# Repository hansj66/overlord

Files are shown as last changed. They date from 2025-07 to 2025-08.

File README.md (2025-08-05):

# Overlord Robot Controller

## Overview

"Overlord" is a carrier board for the Raspberry Pi Compute module 5. The board facilitates easy integration with [Xiaomi Cybergear](https://www.mi.com/cyber-gear) motors and half duplex Dynamixels, like the [AX-12A](https://emanual.robotis.com/docs/en/dxl/ax/ax-12a/), [MX-12W](https://emanual.robotis.com/docs/en/dxl/ax/ax-12a/) servos.

The carrier board has an onboard can controller, can transciever, a 9 axis IMU with 100Hz sensor fusion, half duplex line driver circuitry for Dynamixel servos and has an acceptable power input range from 5 to 36V.

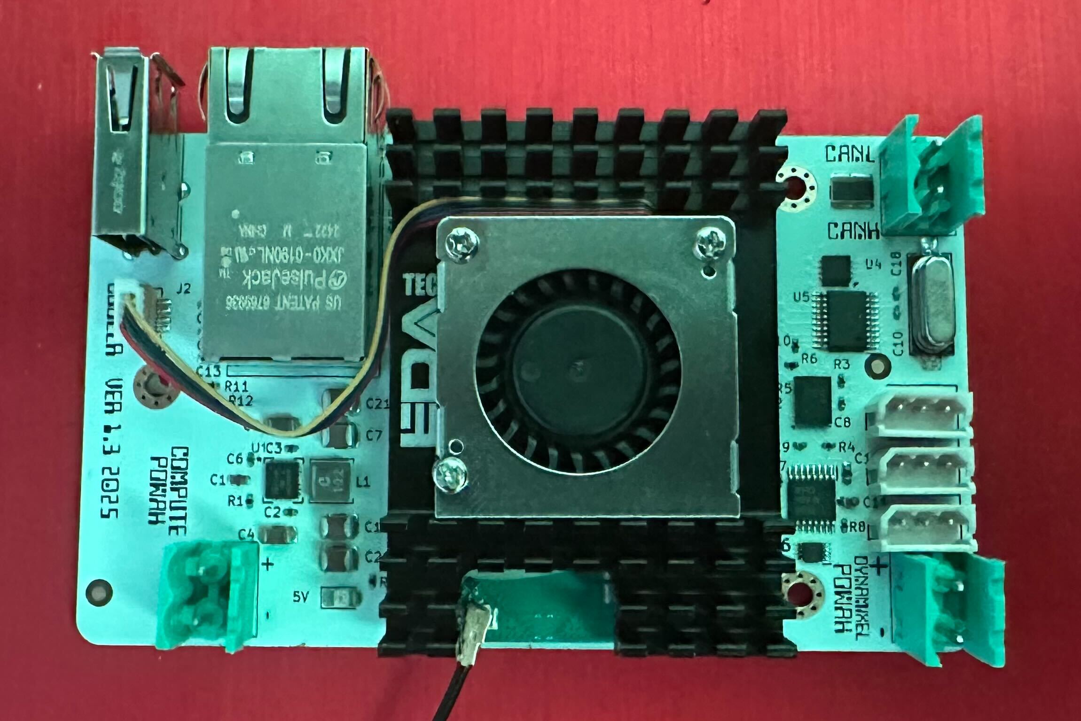
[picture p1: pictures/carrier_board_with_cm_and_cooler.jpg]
Carrier board with CM5 and active cooler


This repository contains:
* All the necessary KiCad schematics, PCB layout and gerber files for making copies of the carrier board.
* boot/firmware/config.txt (for the necessary boot overlays and IO mappings).
* Go code examples for communicating with Dynamixels, Cybergears and the IMU.
* Go code examples for how to implement remote control via a bluetooth gamepad, FrSky [XSR-SIM](https://www.frsky-rc.com/product/xsr-sim/) (or similar HID device).

## Licensing
This is open hardware and software. Licensing terms can be found [here](LICENSE.md).

## Getting started

In addition to the carrier board, you will need a 
* [Compute module 5](https://datasheets.raspberrypi.com/cm5/cm5-datasheet.pdf). 
* [Raspberry Pi Development Kit for Compute Module 5](https://www.raspberrypi.com/products/cm5-dev-kit/)
* If you plan to use wifi, I strongly suggest getting the official Raspberry Pi Compute module 4/5 antenna kit.
* A passive or active cooler for the CM5. If using an active cooler, attach the FAN connector to the "COOLER" socket on the carrier board.

### Programming the CM5

1. The compute module has to be flashed with an operating system before it can be used. Information on how to do this is available in the ["Compute Module Hardware"](https://www.raspberrypi.com/documentation/computers/compute-module.html#flash-compute-module-emmc) section on the offical [raspberrypi.com](https://www.raspberrypi.com/) site. Remember to enable SSH in the OS customisation settings before flashing the module.
1. Mount the CM5 in the carrier board and attach a battery or power supply to the "COMPUTE POWAH" port. Observe polarity. There is no reverse polarity protection circuitry. Reversing polarity will in all likelyhood fry the carrier board.
1. The blue LED on the carrier board will light up, indicating that it has 5V power. 
1. The CM5 will require a few seconds to boot before you can ssh in. (Tip: create an .ssh folder under the CM5 home folder and copy your public key to ./ssh/authorized_keys. You can then "ssh hostname" without having to type in a password)
1. The compute module will announce itself on the network. Given a "hostname", you should now be able to "ssh hostname" to get shell access.
1. Once you have shell access, run "sudo raspi-config" to enable i2c, spi and UART (enable serial port hardware, but not serial shell).
1. Now you can "sudo vi /boot/firmware/config.txt. Update the config.txt according to the [config.txt](./config/config.txt) in this repository. 
1. Run "sudo reboot now" to reboot the module. This makes sure that the correct overlays are loaded and that the GPIO mappings are correct.

You are now all set to start playing around with the board.

## Configuration and code examples

* [Remote control](./firmware/examples/remote-control/README.md)
* [Dynamixel](./firmware/examples/dynamixel/README.md)
* [Xiaomi Cybergear](./firmware/examples/cybergear/README.MD)
* [IMU](./firmware/examples/imu/README.md)

## Networking

This board was designed for simplicity and ease of use with the primary goal being actuator control and balancing. Apart from the onboard IMU, there is no sensing or GPIO access. It is however possible to directly connect the board to another Pi or any other board that supports Auto MDI-X directly using a standard ethernet cable. Access to GPIO, camera etc can then be implemented via a simple tcp client/server.

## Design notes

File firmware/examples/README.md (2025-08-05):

# Overview

The firmware examples aim to demonstrate how to communicate with the hardware at the simplest possible level.

Consider the code samples as examples on how to communicate with peripherals board, not detailed tutorials for how to use Dynamixel servos, Cybergears or the BNO055 IMU etc. The README files accompanying each sample contains a resources chapter with links to relevant documentation and data sheets where control registers, commands and frame formats are documented in detail.

All firmware examples are written in Go, but the same examples are trivial to implement in other languages (C, C++, Python etc)

The example code together with online protocol documentation should be enough to get you started.

1. [Cybergear positioning example](./cybergear/README.MD)
1. [Dynamixel network scan example](./dynamixel/README.md)
1. [IMU example](./imu/README.md)
1. [Remote control example](./remote-control/README.md)

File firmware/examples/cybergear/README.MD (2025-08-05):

# Getting started - Xiaomi Cybergear

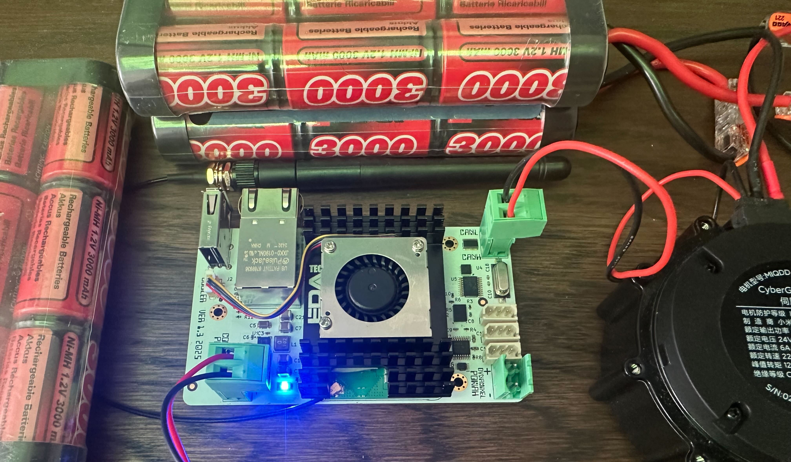
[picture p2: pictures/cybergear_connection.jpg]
cybergear connection


## Verifying that the can interface is ok

1. Install can utils

```sh
sudo apt install can-utils
```

2. Verify that the MCP2515 driver is initialized

```sh
dmesg | grep -i mcp
```
This should generate the following response:
```sh
mcp251x spi0.0 can0: MCP2515 successfully initialized.
```

3. Bring up can0.
```sh
sudo ip link set can0 up type can bitrate 1000000
```

## Initial test

With the board still powered up (battery / powersupply) connected to the "COMPUTE POWAH" port.

1. Connect the thin red wire from the Amass XT30(2+2) connector to CANH on the board.
2. Connect the thin black wire from the Amass XT30(2+2) connector to CANL on the board
3. Run the following command from the ssh shell

```sh
candump can0
```

candump is now running. 

Now you can connect power to the Cybergear via the thick red and black wires on the Amass XT30(2+2) connector. You should now see the following output from candump (0x7F is the default motor address):

```sh
can0  00007FFE   [8]  41 11 31 31 30 33 31 0A
```

### Code examples

* [position example README](./position/README.md)
* [position example code](./position/position.go)

### Resources

* [English translation of the Cybergear manual](https://github.com/belovictor/cybergear-docs/blob/main/instructionmanual/instructionmanual.md). This contains a description of the frame format and commands.
* [Open ELAB manual](https://openelab.io/blogs/learn/xiaomi-cybergear-motor-driver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)

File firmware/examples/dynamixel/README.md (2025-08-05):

# Getting started - Dynamixel

## Parametrization

Dynamixel servos have EEPROM + RAM control tables for parametrization (ID, baud rate, voltage limits etc). Since all servos are daisy chained and connected to the same communication bus, you will have to configure the servo ID and communication baud rate for each servo. This can be done in code, using [DYNAMIXEL protocol 2.0](https://emanual.robotis.com/docs/en/dxl/protocol2/) for AX-12A servos or [DYNAMIXEL protocol 1.0](https://emanual.robotis.com/docs/en/dxl/protocol1/) for MX-12W servos.

Since it is relatively easy to shoot yourself in the foot when parametrizing these servos (by changing baud rate etc), I highly recommend getting hold of a [U2D2 USB Communication converter](https://emanual.robotis.com/docs/en/parts/interface/u2d2/). Servo power has to be provided externally. You can use a separate power distributuion board together with the U2D2 when parametrizing the servos, or you can connect the U2D2 to the CM5 carrier board.

1. Connect the U2D2 to one of the dynamixel sockets on the carrier board.
1. Connect the U2D2 to your computer using a USB micro B to USBA cable.
1. Connect your servo to one of the remaining ports (multiple servos can be connected in serial by daisy chaining them).
1. Connect a battery pack or power supply to the "DYNAMIXEL POWAH" connector. Observe polarity, since this feeds directly into the servo power line. Do not connect anything to "COMPUTE POWAH" when doing this, since the carrier board just acts as a power distribution board / hub for the U2D2 when we parametrize the control tables.

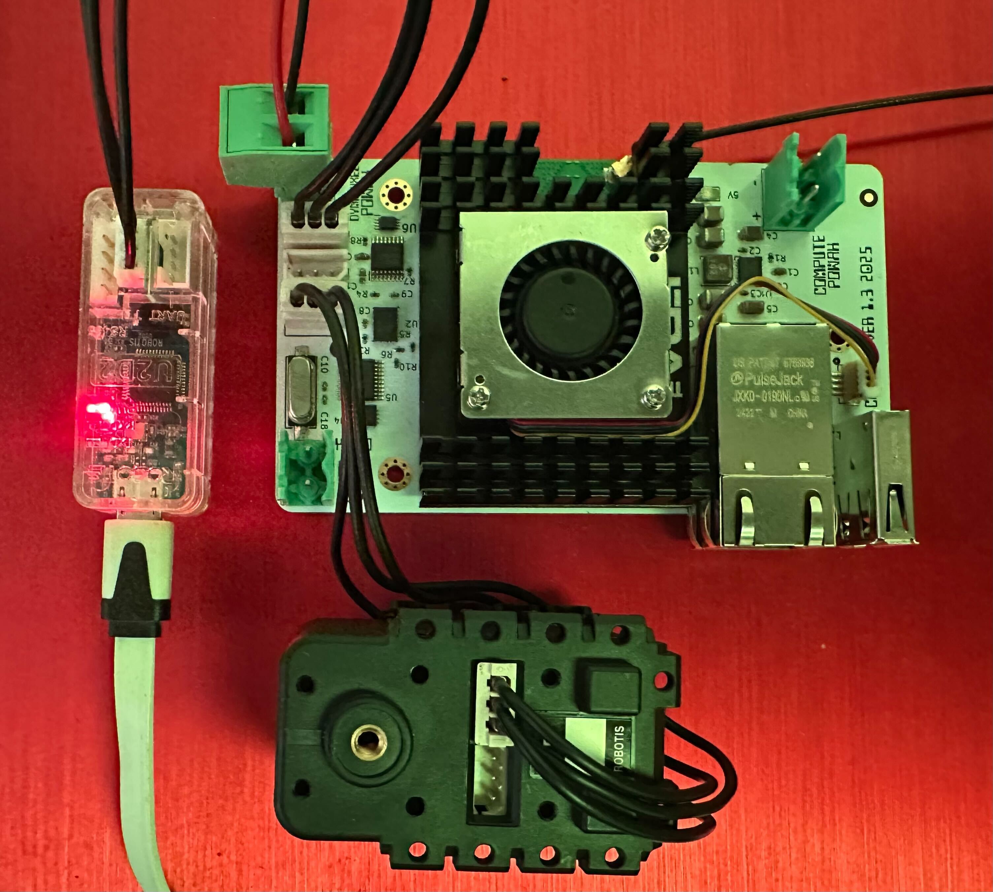
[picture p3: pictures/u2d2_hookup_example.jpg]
U2D2 hookup example


Once everything is hooked up and servo power is applied, you can use [Dynamixel Wizard](https://emanual.robotis.com/docs/en/software/dynamixel/dynamixel_wizard2/) to scan for servos in the network and also configure them (ID, baud rate etc)

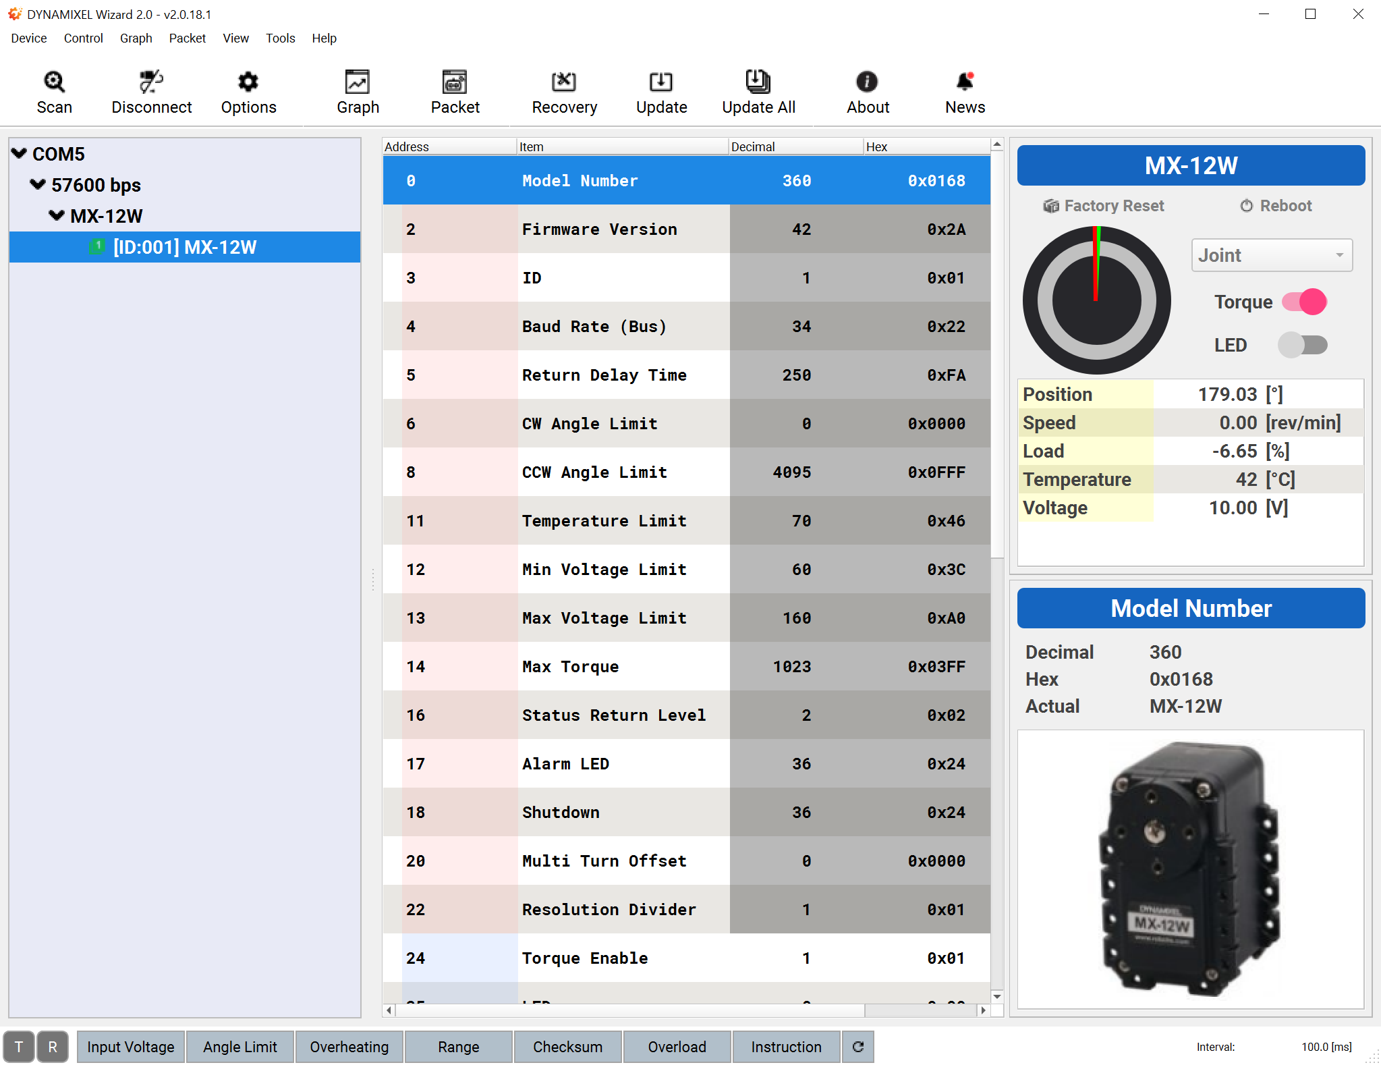
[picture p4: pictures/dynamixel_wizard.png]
Dynamixel wizard screen shot


> Note: If you are feeling brave, it is entirely possible to do this parametrization in code, but that means that someone (most likely you) will have to write a bit of extra code before you can play around with the servos and the controller board:)

### Code examples

* [Network scan example README](./scan/README.md)
* [Network scan example code](./scan/scan.go)

### Resources

* [Dynamixel SDK](https://emanual.robotis.com/docs/en/software/dynamixel/dynamixel_sdk/overview/)
* [Dynamixel Protocol 1.0](https://emanual.robotis.com/docs/en/dxl/protocol1/)
* [Dynamixel Protocol 2.0](https://emanual.robotis.com/docs/en/dxl/protocol2/)
* [Dynamxiel Wizard](https://emanual.robotis.com/docs/en/software/dynamixel/dynamixel_wizard2/)
* [U2D2 interface](https://emanual.robotis.com/docs/en/parts/interface/u2d2/)

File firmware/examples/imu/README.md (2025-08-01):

# IMU

Note: AFAIK there is no kernel driver available for the BNO055 IMU, so the low level i2c interface must be used to communicate witht the IMU.

## Cross compiling the Go example code

1. Set the following environment variables (syntax may vary depending on your OS flavour),

```sh
GOOS=linux 
GOARCH=arm64 
GOARM=8
```

2. Compile the example program 

```sh
go build -o euler
```

3. Upload the binary to your board using scp (host name is "overlord" in the example)

```sh
scp euler overlord:
```

4. ssh to your board and run the euler program (chmod +x if it isn't executable)

```sh
ssh overlord
chmod +x euler
./euler
```

Move the carrier board around to see the heading vector change.
Example output:

```sh
2025/08/01 16:47:14 INFO BNO055 heading="Heading: 357.75°, Roll: 4066.62°, Pitch: 11.19°\n"
2025/08/01 16:47:14 INFO BNO055 heading="Heading: 359.56°, Roll: 4037.38°, Pitch: 43.06°\n"
2025/08/01 16:47:15 INFO BNO055 heading="Heading: 358.31°, Roll: 4027.44°, Pitch: 21.00°\n"
2025/08/01 16:47:15 INFO BNO055 heading="Heading: 340.94°, Roll: 4033.19°, Pitch: 4028.31°\n"
2025/08/01 16:47:16 INFO BNO055 heading="Heading: 76.75°, Roll: 4048.81°, Pitch: 4020.38°\n"
2025/08/01 16:47:16 INFO BNO055 heading="Heading: 81.56°, Roll: 4067.94°, Pitch: 4029.06°\n"
2025/08/01 16:47:17 INFO BNO055 heading="Heading: 73.81°, Roll: 4089.69°, Pitch: 4020.50°\n"
2025/08/01 16:47:17 INFO BNO055 heading="Heading: 74.81°, Roll: 4085.62°, Pitch: 4060.06°\n"
2025/08/01 16:47:18 INFO BNO055 heading="Heading: 82.56°, Roll: 4089.88°, Pitch: 1.00°\n"
```

### Resources

* [BNO055 Datasheet](https://www.bosch-sensortec.com/media/boschsensortec/downloads/datasheets/bst-bno055-ds000.pdf)
* [BNO055 no-os driver](https://github.com/boschsensortec/BNO055_SensorAPI)

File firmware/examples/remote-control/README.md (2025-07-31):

# Remote control

An ordinary gamepad can be used for remote control of the carrier board. In this example we'll use a generic gamepad with a bluetooth USB dongle. This will appear as a HID device on the CM5 and will be accessible as /dev/input/js0

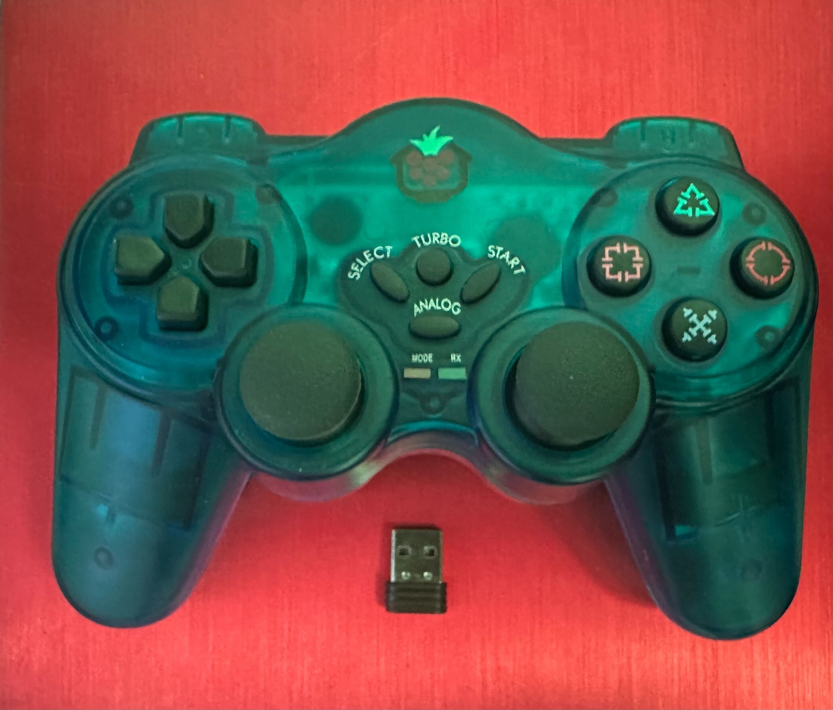
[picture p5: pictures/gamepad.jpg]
Generic gamepad with USB dongle


The example program is meant as an illustration of how to access the input HID device and decode events from the gamepad. 

## Cross compiling the Go example code

1. Set the following environment variables (syntax may vary depending on your OS flavour),

```sh
GOOS=linux 
GOARCH=arm64 
GOARM=8
```

2. Compile the example program 

```sh
go build -o joysticktest
```

3. Upload the binary to your board using scp (host name is "overlord" in the example)

```sh
scp joysticktest overlord:
```

4. ssh to your board and run the joysticktest program (chmod +x if it isn't executable)

```sh
ssh overlord
chmod +x joysticktest
./joysticktest
```

The program will list the status of all gamepad buttons and axis. Pressing a button or moving one of the axis will result in an event that is listed on the screen.

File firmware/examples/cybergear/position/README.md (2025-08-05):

## Positioning example

This example first runs the motor in speedmode with two different speeds / directions and then runs the motor in positioning mode where it toggles between 0 and +90° five times.

## Cross compiling and running the Go example code

1. Set the following environment variables (syntax may vary depending on your OS flavour),

```sh
GOOS=linux 
GOARCH=arm64 
GOARM=8
```

2. Compile the example program 

```sh
go build -o position
```

3. Upload the binary to your board using scp (host name is "overlord" in the example)

```sh
scp position overlord:
```

4. Bring up the CAN bus

```sh
sudo ip link set can0 up type can bitrate 1000000
```

4. ssh to your board and run the scan program (chmod +x if it isn't executable)

```sh
ssh overlord
chmod +x position
./scan
```

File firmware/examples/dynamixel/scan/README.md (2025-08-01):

# Dynamixel Protocol 1.0 network scan

This example demonstrates how to scan the valid servo ID range. This is done by sending a ping packet to all addresses between 0 and 253. A response packet indicates that a servo has been found in the network

This example is using Dynamixel protocol 1.0 for sending ping packets. The example can be modified for using protocol 2.0 by changing the frame format and CRC calculation. Protocol 2.0 ping is described in section 5.1.3.2 in this manual: https://emanual.robotis.com/docs/en/dxl/protocol2/

## Cross compiling the Go example code

1. Set the following environment variables (syntax may vary depending on your OS flavour),

```sh
GOOS=linux 
GOARCH=arm64 
GOARM=8
```

2. Compile the example program 

```sh
go build -o scan
```

3. Upload the binary to your board using scp (host name is "overlord" in the example)

```sh
scp scan overlord:
```

4. ssh to your board and run the scan program (chmod +x if it isn't executable)

```sh
ssh overlord
chmod +x scan
./scan
```

Assuming that the network contains one servo with ID=1, the output will be on the form:

```sh
2025/08/01 14:09:41 INFO Opening serialport port=/dev/ttyAMA0
2025/08/01 14:09:41 INFO Serial port opened successfully
2025/08/01 14:09:41 INFO DXL DIR pin=GPIO22
PING id:0 - no response
PING id:1 - response packet: FFFF010200FC
PING id:2 - no response
PING id:3 - no response
...
```

The same protocol can be used for reading and writing to EEPROM and RAM control table parameters
Protocol specifications:
 - 1.0: https://emanual.robotis.com/docs/en/dxl/protocol1/
 - 2.0: https://emanual.robotis.com/docs/en/dxl/protocol2/

Note:

1. The carrier board has to be powered through the "COMPUTE POWAH" connector (5-36V).
1. The dynamixel servos has to be powered through the "DYNAMIXEL POWAH". This power rail only feeds the
   servos via the dynamixel bus. Please refer to the servo manuals regarding min/max voltages. Exceeding
   the rated servo voltages will permanently damage your servos.

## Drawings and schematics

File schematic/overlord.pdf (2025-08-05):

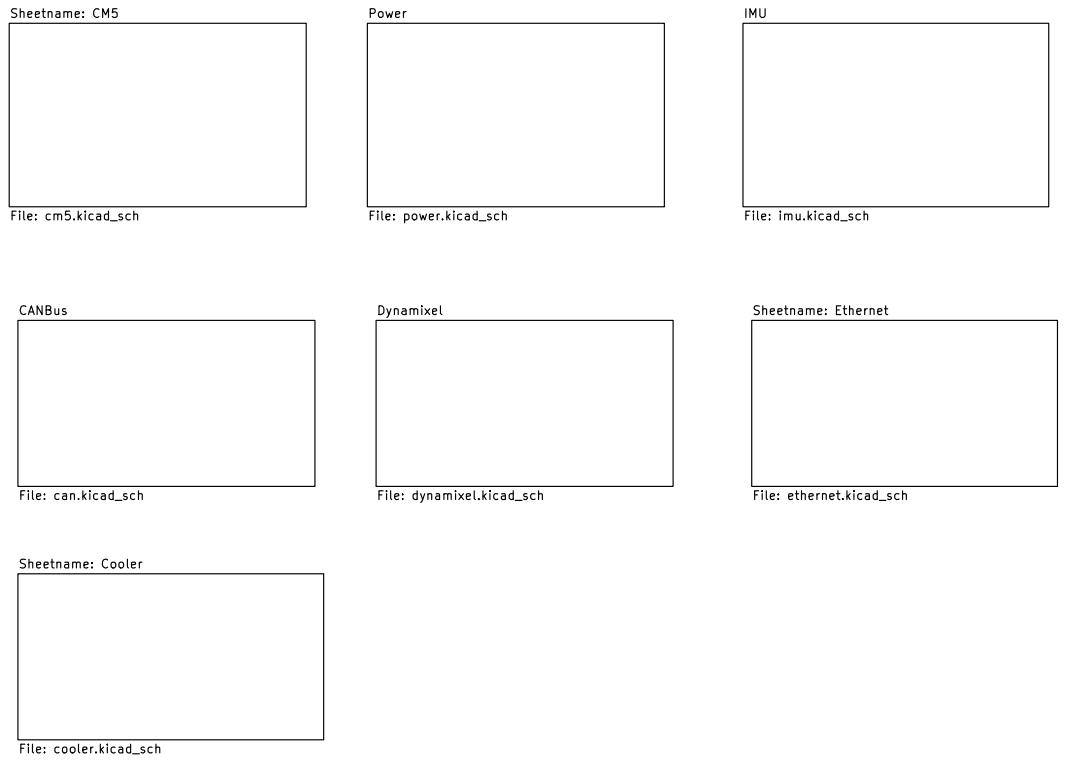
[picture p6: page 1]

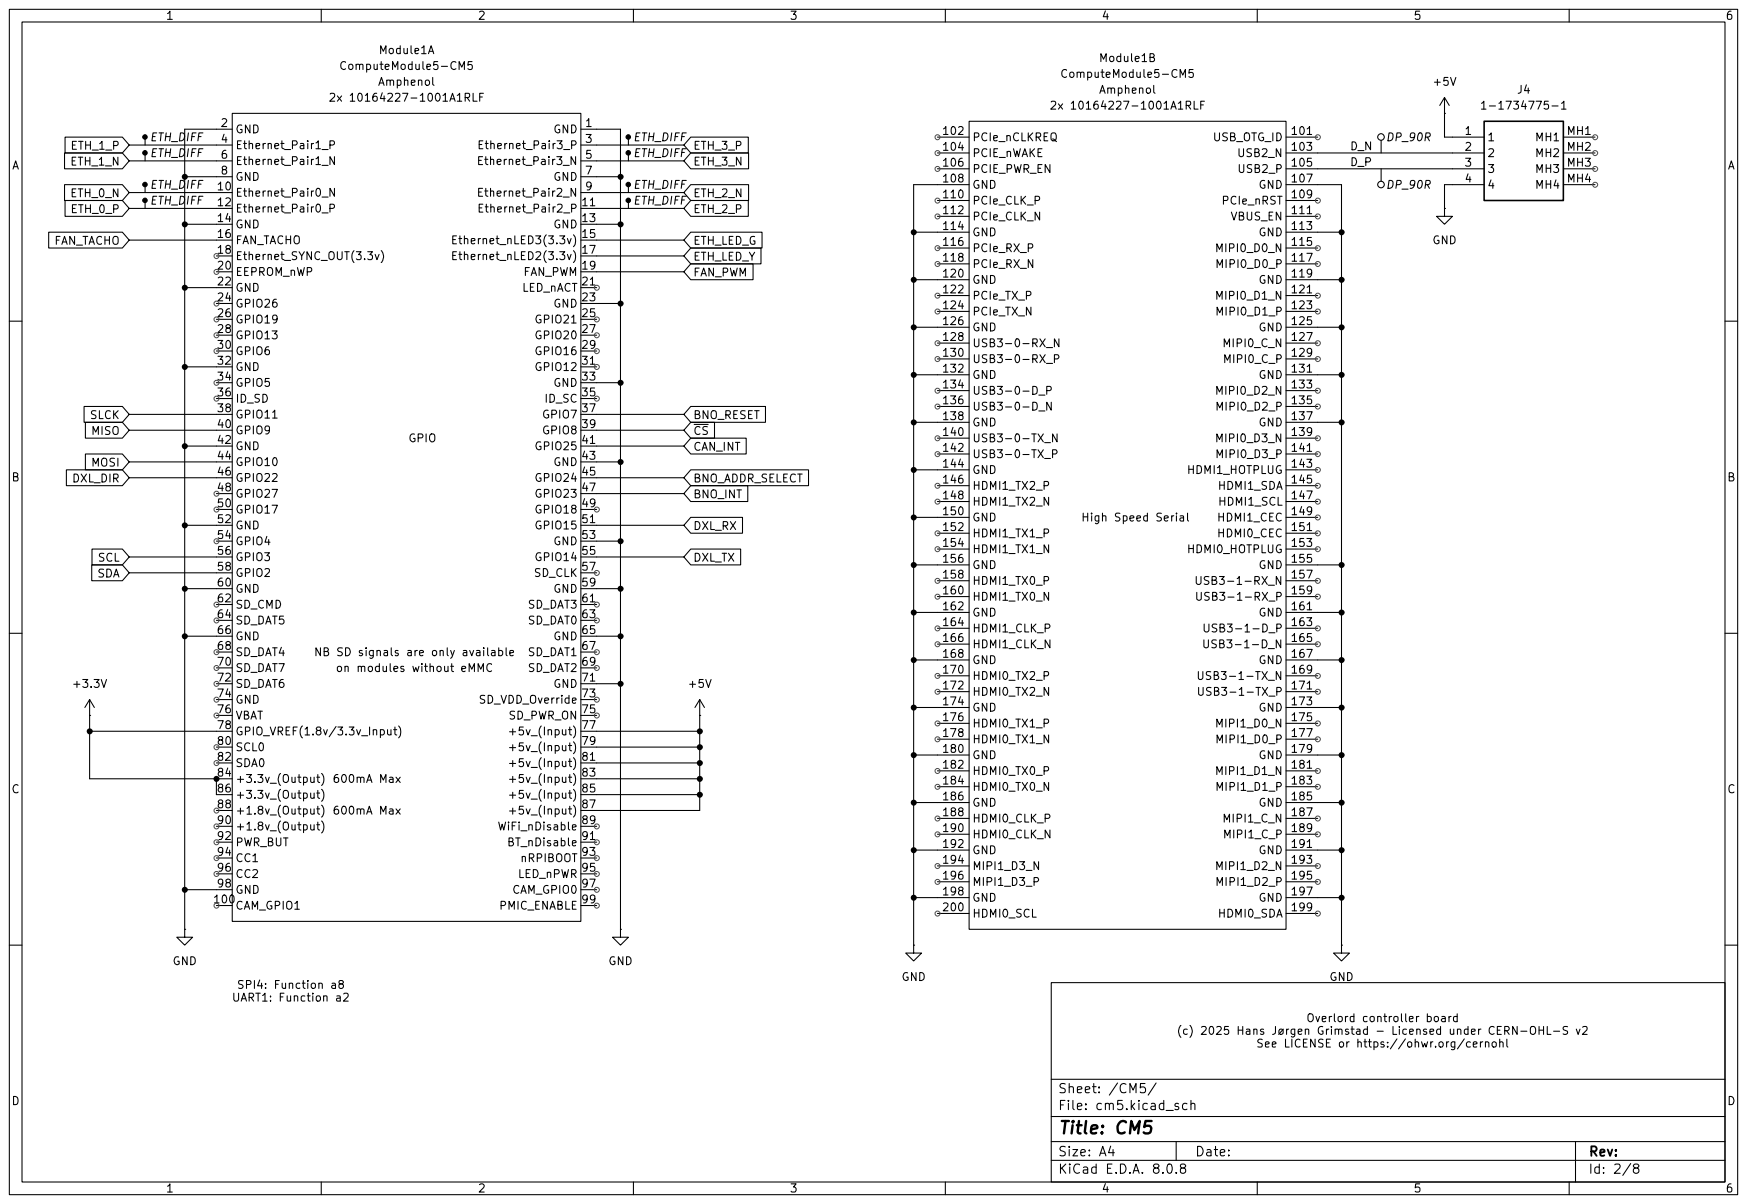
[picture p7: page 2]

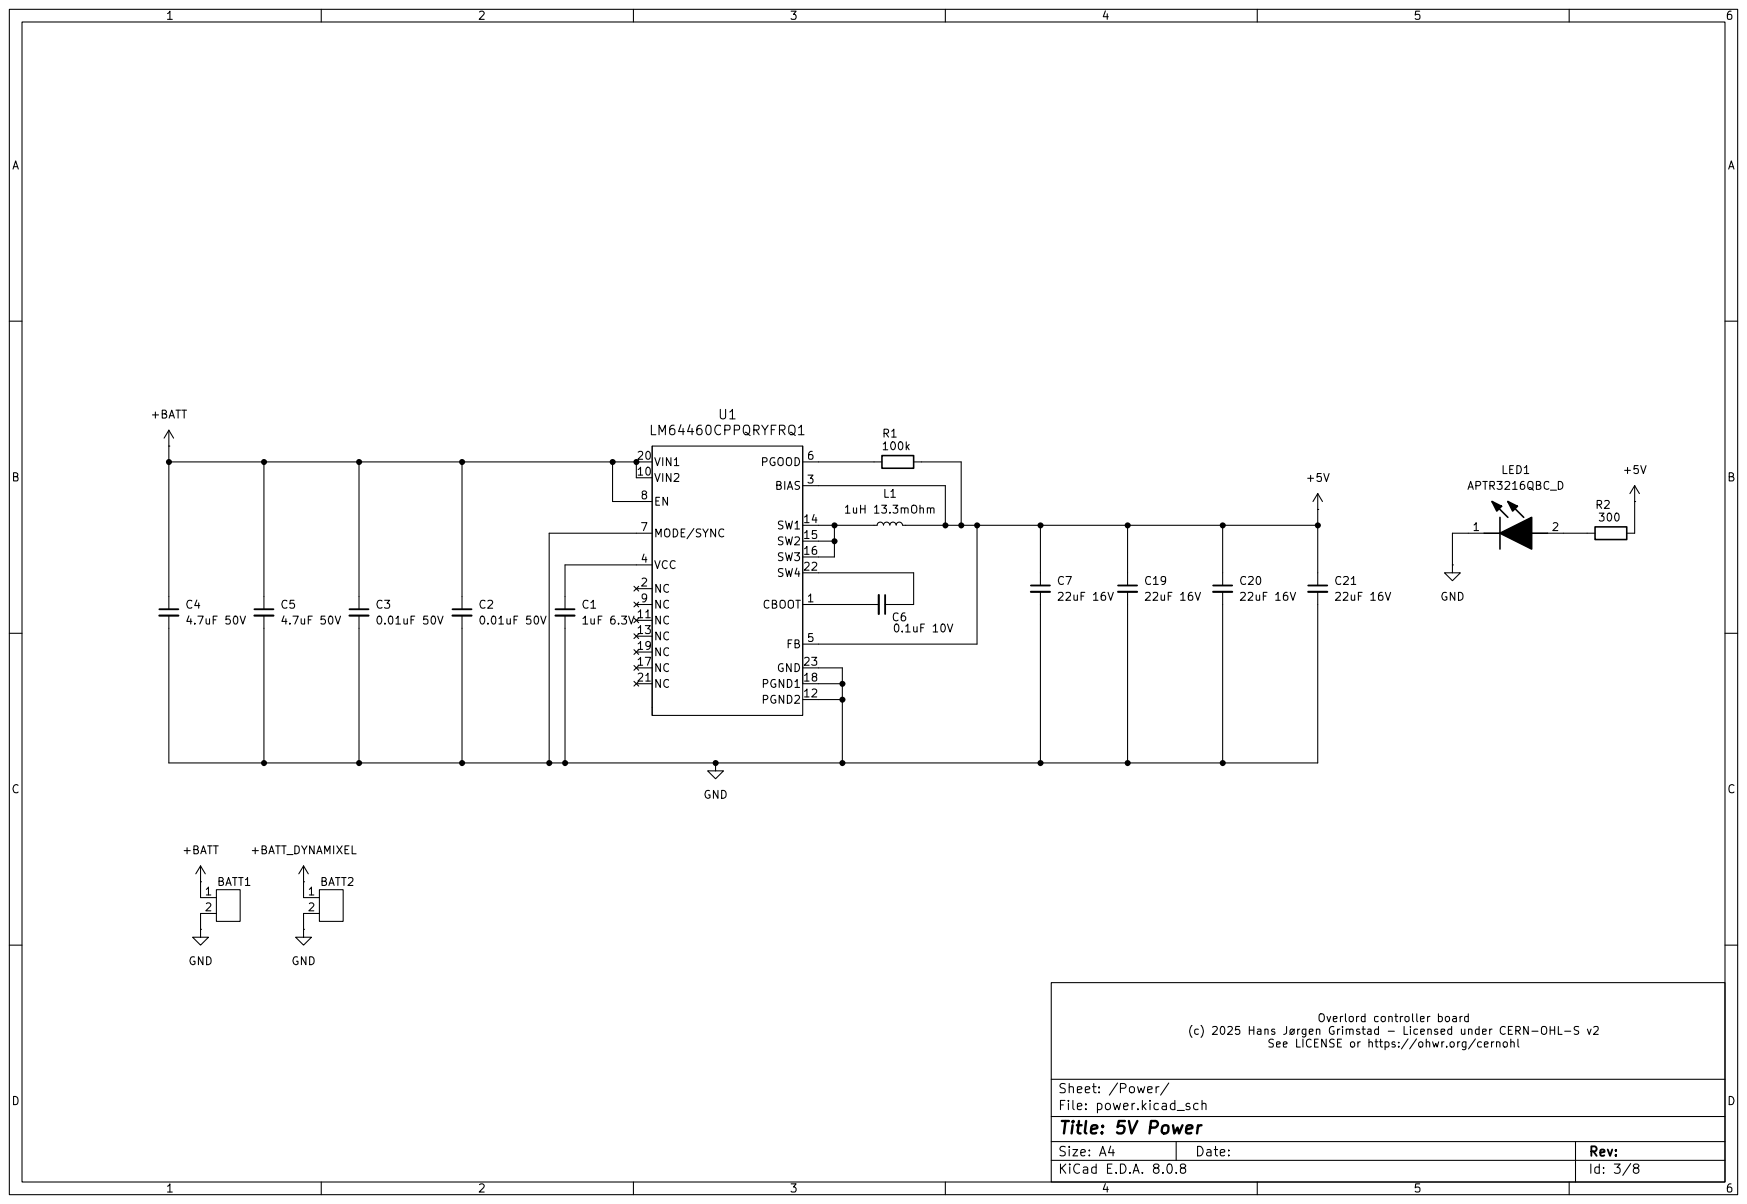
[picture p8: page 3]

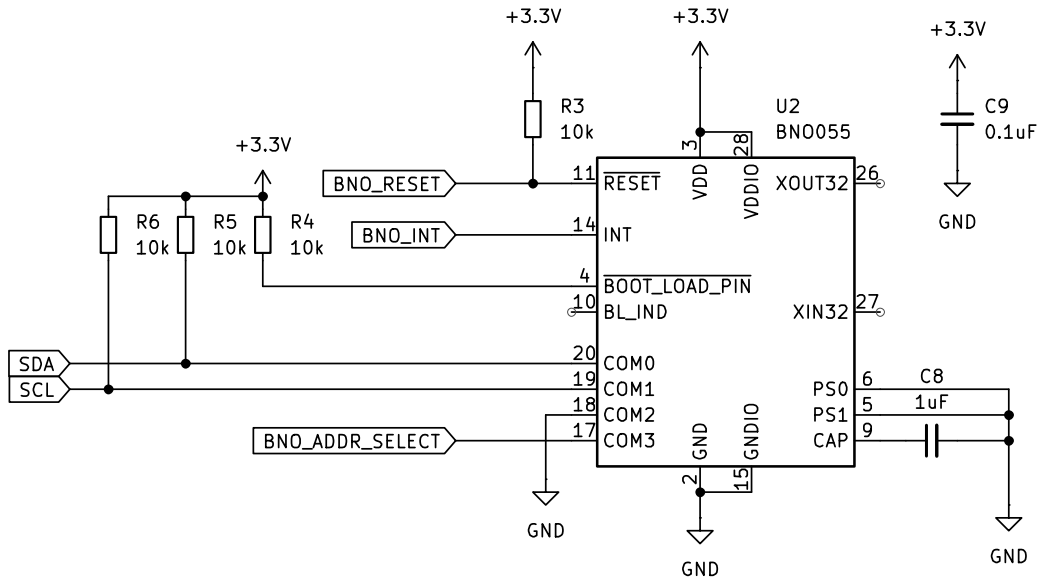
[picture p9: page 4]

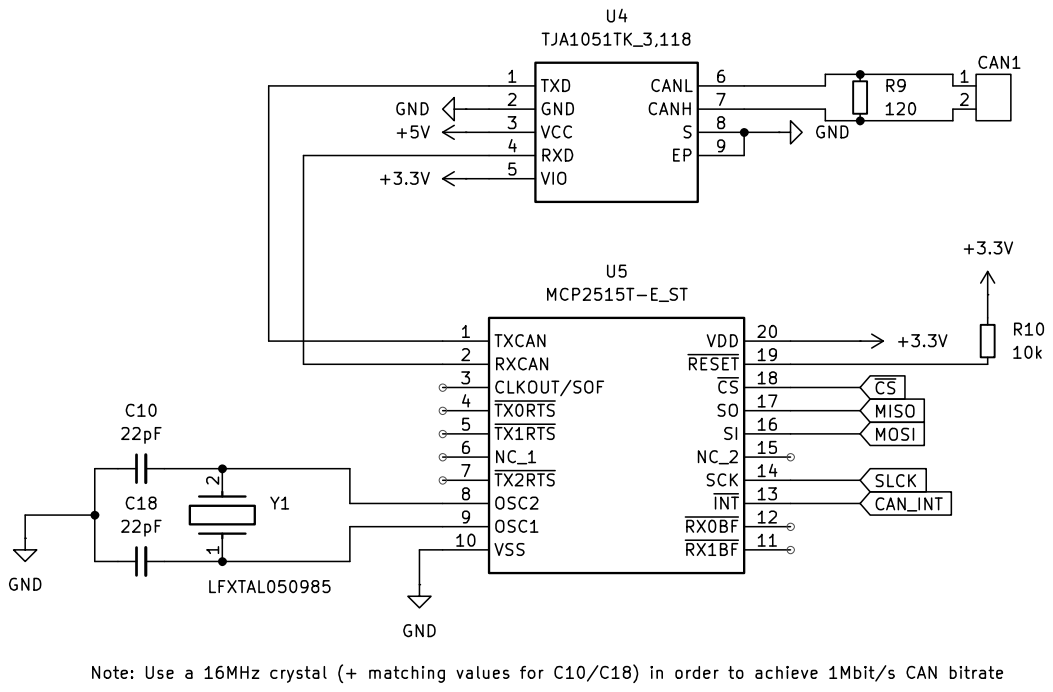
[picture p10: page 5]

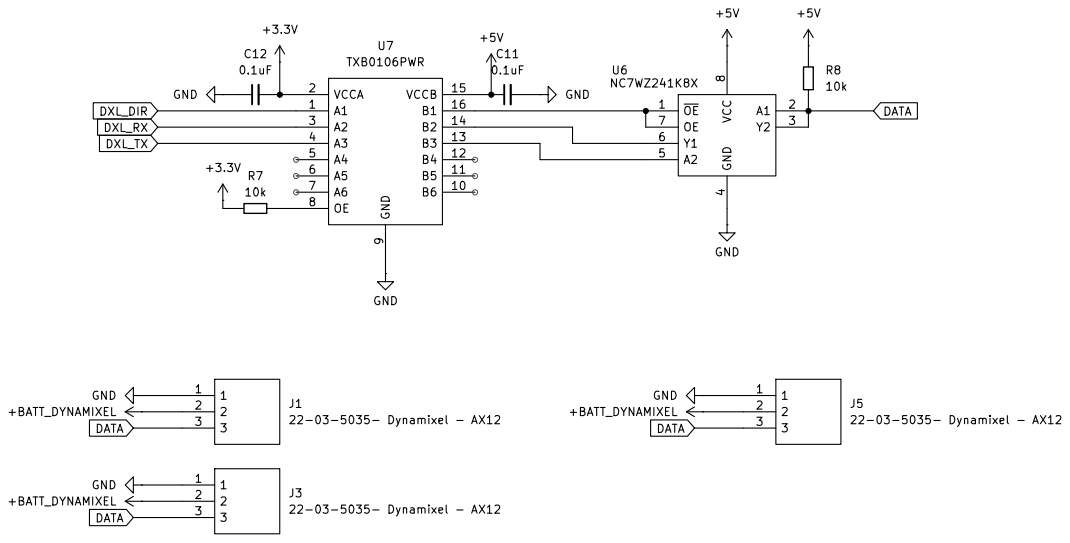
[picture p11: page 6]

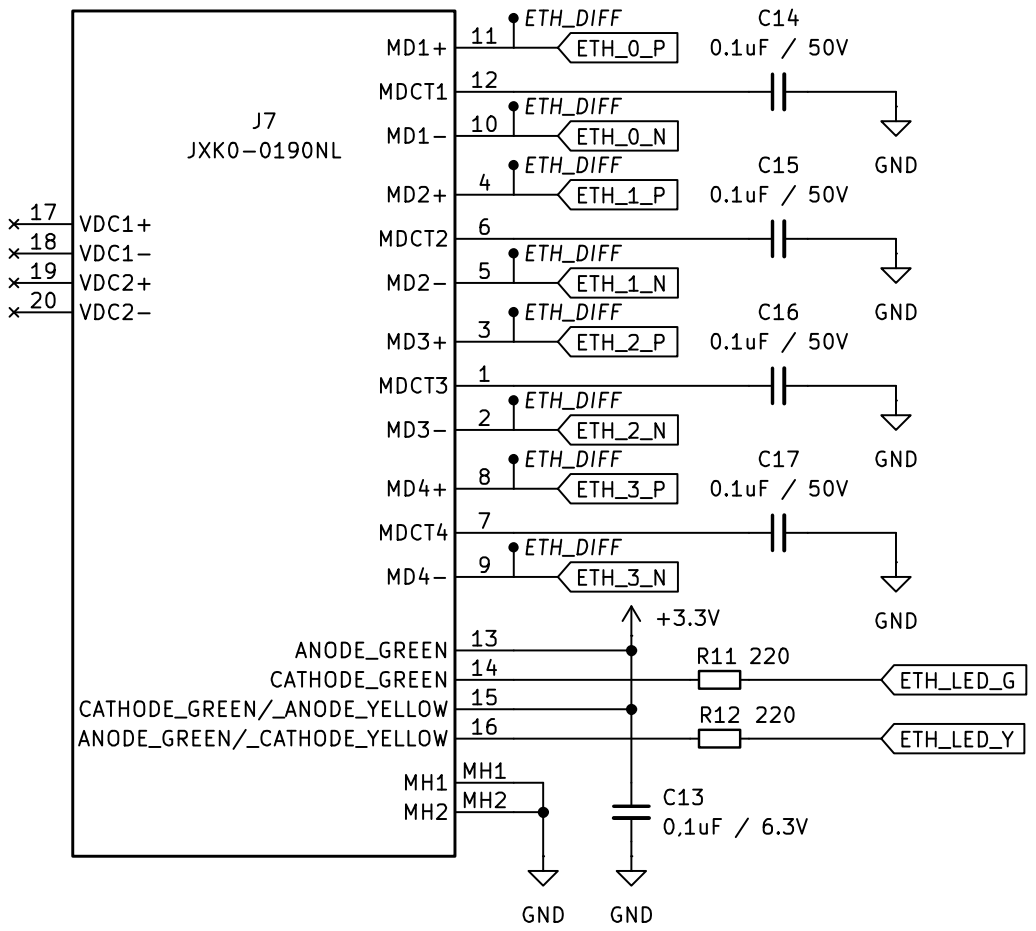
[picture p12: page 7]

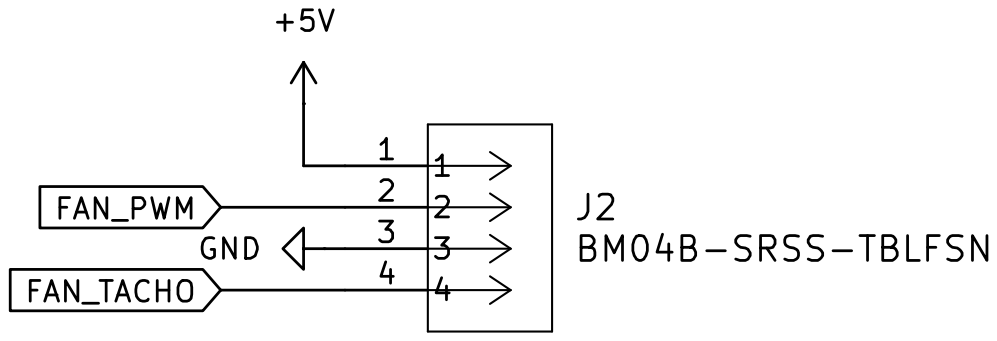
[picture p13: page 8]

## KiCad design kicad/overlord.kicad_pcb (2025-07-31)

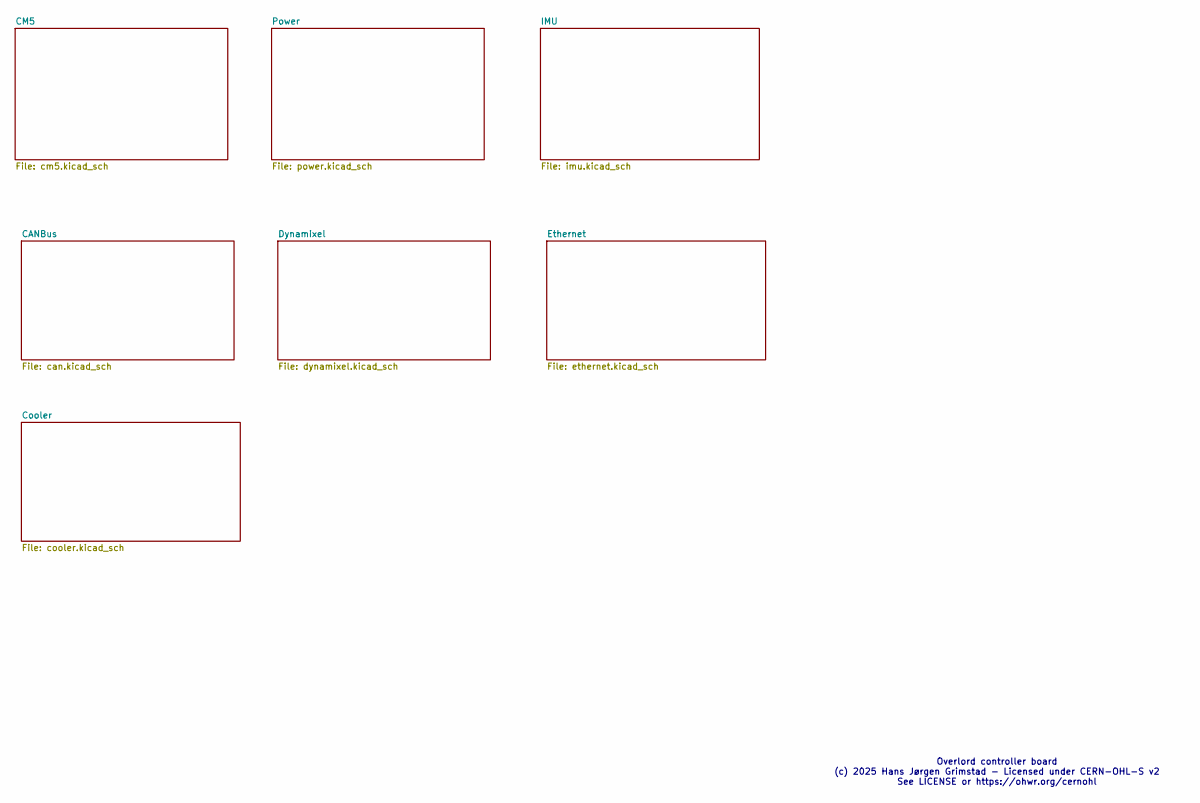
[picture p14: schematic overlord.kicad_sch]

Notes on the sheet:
Overlord controller board (c) 2025 Hans Jørgen Grimstad - Licensed under CERN-OHL-S v2 See LICENSE or https://ohwr.org/cernohl

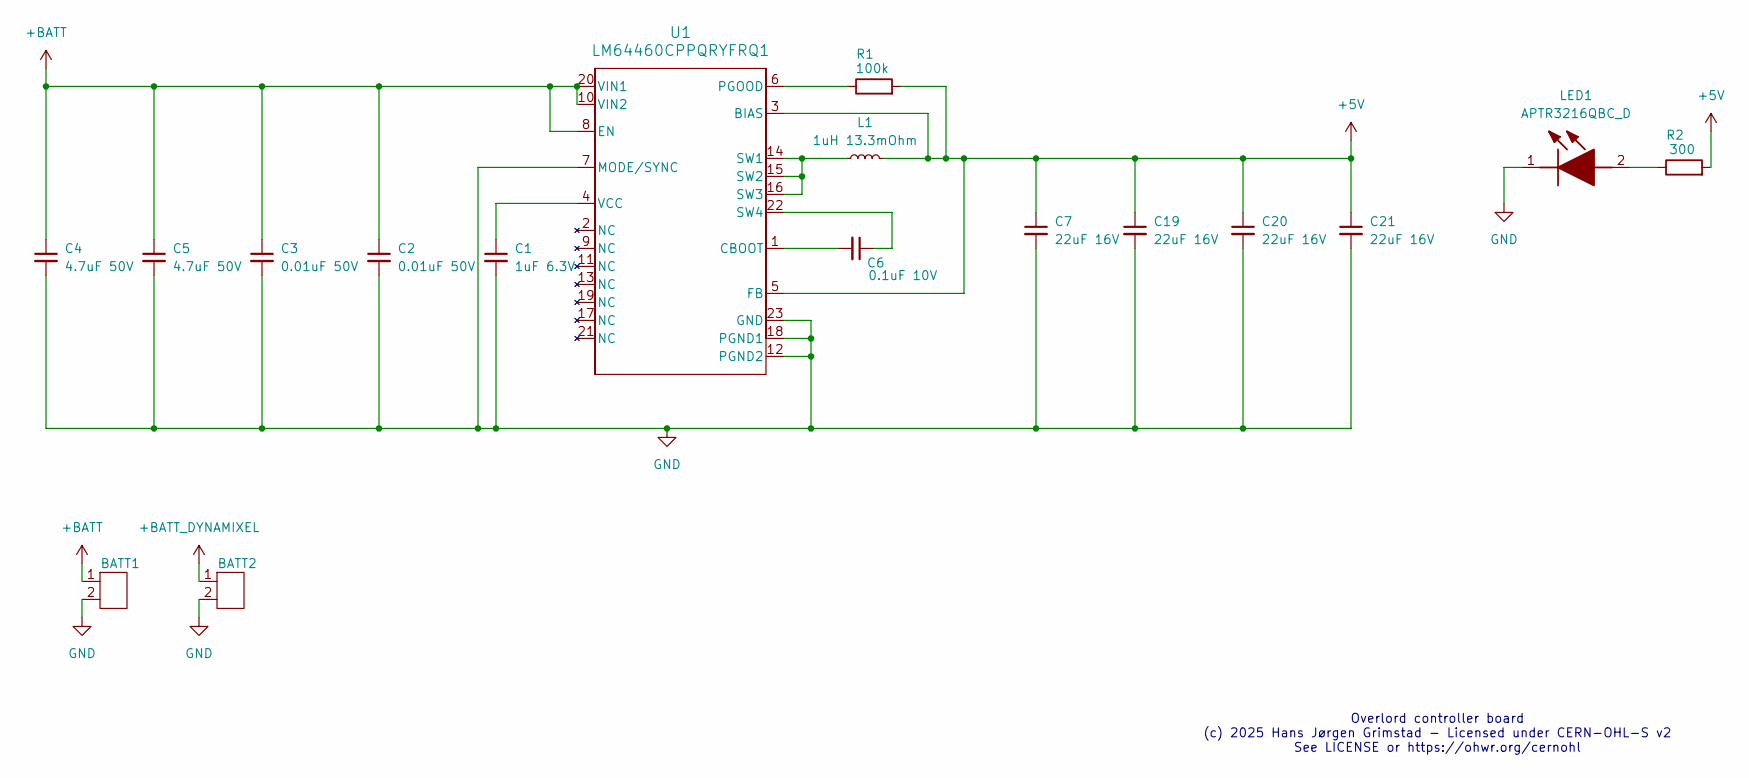
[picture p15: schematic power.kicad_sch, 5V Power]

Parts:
BATT1, BATT2: MOLEX-39531-5002
C1: 1uF 6.3V; C_0603_1608Metric
C2, C3: 0.01uF 50V; C_0402_1005Metric
C4, C5: 4.7uF 50V; C_1206_3216Metric
C6: 0.1uF 10V; C_0402_1005Metric
C7, C19, C20, C21: 22uF 16V; C_1210_3225Metric
L1: 1uH 13.3mOhm; L_Coilcraft_XAL4020-XXX
LED1: APTR3216QBC_D; LED_1206_3216Metric; Mouser Part Number 604-APTR3216QBC/D
R1: 100k; R_0402_1005Metric
R2: 300; R_0402_1005Metric
U1: LM64460CPPQRYFRQ1; VQFN22_RYF_TEX

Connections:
+5V: C7.1, C19.1, C20.1, C21.1, L1.2, R1.2, R2.2, U1.3 (BIAS), U1.5 (FB); also elsewhere on the board
+BATT: BATT1.1, C2.1, C3.1, C4.1, C5.1, U1.8 (EN), U1.10 (VIN2), U1.20 (VIN1)
+BATT_DYNAMIXEL: BATT2.1; also elsewhere on the board
GND: BATT1.2, BATT2.2, C1.2, C2.2, C3.2, C4.2, C5.2, C7.2, C19.2, C20.2, C21.2, U1.7 (MODE/SYNC), U1.12 (PGND2), U1.18 (PGND1), U1.23 (GND); also elsewhere on the board
unnamed 35: LED1.2 (A), R2.1; also elsewhere on the board
unnamed: C6.2, U1.1 (CBOOT)
unnamed: R1.1, U1.6 (PGOOD)
unnamed: L1.1, U1.14 (SW1), U1.15 (SW2), U1.16 (SW3)
unnamed: C6.1, U1.22 (SW4)
unnamed: C1.1, U1.4 (VCC)

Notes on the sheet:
Overlord controller board (c) 2025 Hans Jørgen Grimstad - Licensed under CERN-OHL-S v2 See LICENSE or https://ohwr.org/cernohl

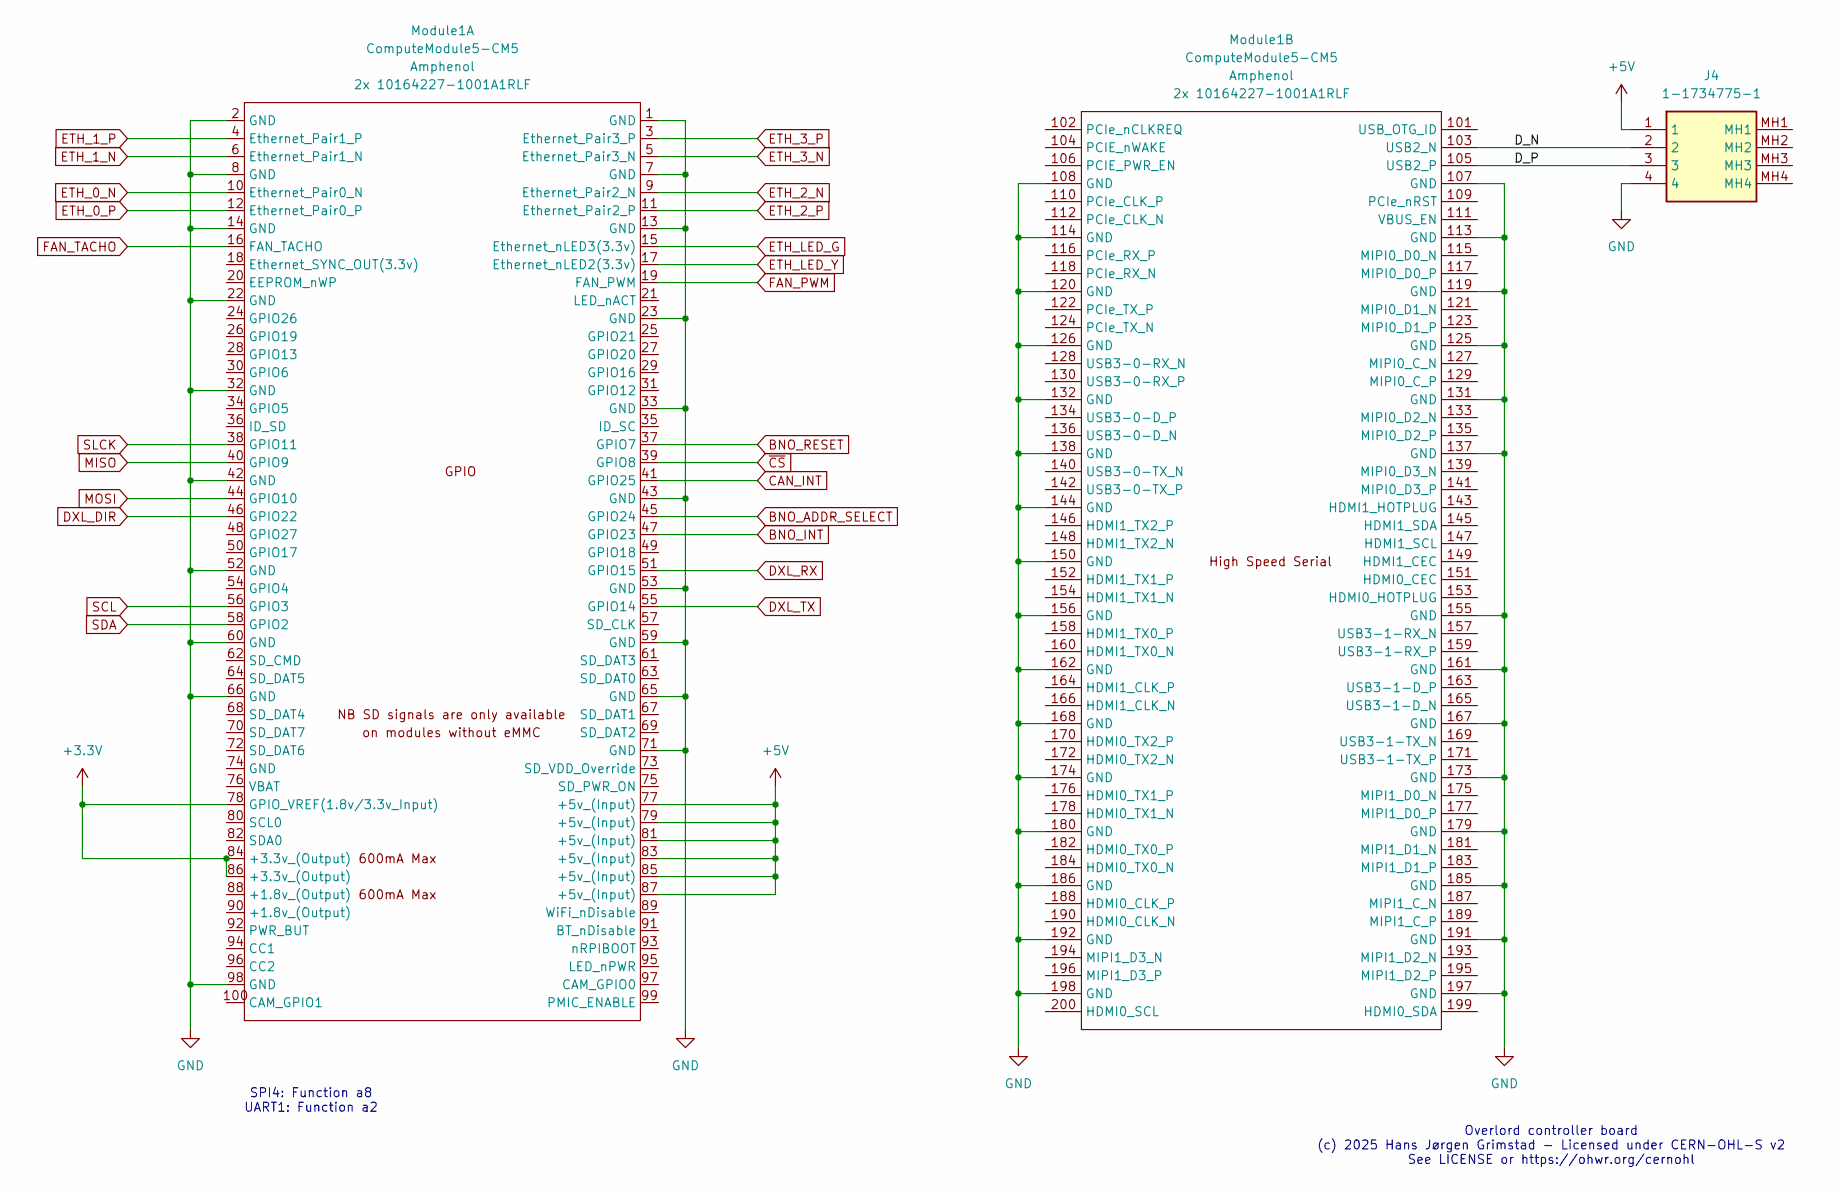
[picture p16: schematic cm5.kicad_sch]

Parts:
J4: 1-1734775-1; 117347751; Mouser Part Number 571-1-1734775-1
Module1: ComputeModule5-CM5; Raspberry-Pi-5-Compute-Module

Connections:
+3.3V: Module1.78 (GPIO_VREF(1.8v/3.3v_Input)), Module1.84 (+3.3v_(Output)), Module1.86 (+3.3v_(Output)); also elsewhere on the board
+5V: J4.1, Module1.77 (+5v_(Input)), Module1.79 (+5v_(Input)), Module1.81 (+5v_(Input)), Module1.83 (+5v_(Input)), Module1.85 (+5v_(Input)), Module1.87 (+5v_(Input)); also elsewhere on the board
/CM5/DN: J4.3, Module1.105 (USB2_P)
/CM5/DP: J4.2, Module1.103 (USB2_N)
BNO_ADDR_SELECT: Module1.45 (GPIO24); also elsewhere on the board
BNO_INT: Module1.47 (GPIO23); also elsewhere on the board
BNO_RESET: Module1.37 (GPIO7); also elsewhere on the board
CAN_INT: Module1.41 (GPIO25); also elsewhere on the board
DXL_DIR: Module1.46 (GPIO22); also elsewhere on the board
DXL_RX: Module1.51 (GPIO15); also elsewhere on the board
DXL_TX: Module1.55 (GPIO14); also elsewhere on the board
ETH_0_N: Module1.10 (Ethernet_Pair0_N); also elsewhere on the board
ETH_0_P: Module1.12 (Ethernet_Pair0_P); also elsewhere on the board
ETH_1_N: Module1.6 (Ethernet_Pair1_N); also elsewhere on the board
ETH_1_P: Module1.4 (Ethernet_Pair1_P); also elsewhere on the board
ETH_2_N: Module1.9 (Ethernet_Pair2_N); also elsewhere on the board
ETH_2_P: Module1.11 (Ethernet_Pair2_P); also elsewhere on the board
ETH_3_N: Module1.5 (Ethernet_Pair3_N); also elsewhere on the board
ETH_3_P: Module1.3 (Ethernet_Pair3_P); also elsewhere on the board
ETH_LED_G: Module1.15 (Ethernet_nLED3(3.3v)); also elsewhere on the board
ETH_LED_Y: Module1.17 (Ethernet_nLED2(3.3v)); also elsewhere on the board
FAN_PWM: Module1.19 (FAN_PWM); also elsewhere on the board
FAN_TACHO: Module1.16 (FAN_TACHO); also elsewhere on the board
GND: J4.4, Module1.1 (GND), Module1.2 (GND), Module1.7 (GND), Module1.8 (GND), Module1.13 (GND), Module1.14 (GND), Module1.22 (GND), Module1.23 (GND), Module1.32 (GND), Module1.33 (GND), Module1.42 (GND), Module1.43 (GND), Module1.52 (GND), Module1.53 (GND), Module1.59 (GND), Module1.60 (GND), Module1.65 (GND), Module1.66 (GND), Module1.71 (GND), Module1.98 (GND), Module1.107 (GND), Module1.108 (GND), Module1.113 (GND), Module1.114 (GND), Module1.119 (GND), Module1.120 (GND), Module1.125 (GND), Module1.126 (GND), Module1.131 (GND), Module1.132 (GND), Module1.137 (GND), Module1.138 (GND), Module1.144 (GND), Module1.150 (GND), Module1.155 (GND), Module1.156 (GND), Module1.161 (GND), Module1.162 (GND), Module1.167 (GND), Module1.168 (GND), Module1.173 (GND), Module1.174 (GND), Module1.179 (GND), Module1.180 (GND), Module1.185 (GND), Module1.186 (GND), Module1.191 (GND), Module1.192 (GND), Module1.197 (GND), Module1.198 (GND); also elsewhere on the board
MISO: Module1.40 (GPIO9); also elsewhere on the board
MOSI: Module1.44 (GPIO10); also elsewhere on the board
SCL: Module1.56 (GPIO3); also elsewhere on the board
SDA: Module1.58 (GPIO2); also elsewhere on the board
SLCK: Module1.38 (GPIO11); also elsewhere on the board
~CS: Module1.39 (GPIO8); also elsewhere on the board

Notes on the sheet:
SPI4: Function a8 UART1: Function a2
Overlord controller board (c) 2025 Hans Jørgen Grimstad - Licensed under CERN-OHL-S v2 See LICENSE or https://ohwr.org/cernohl

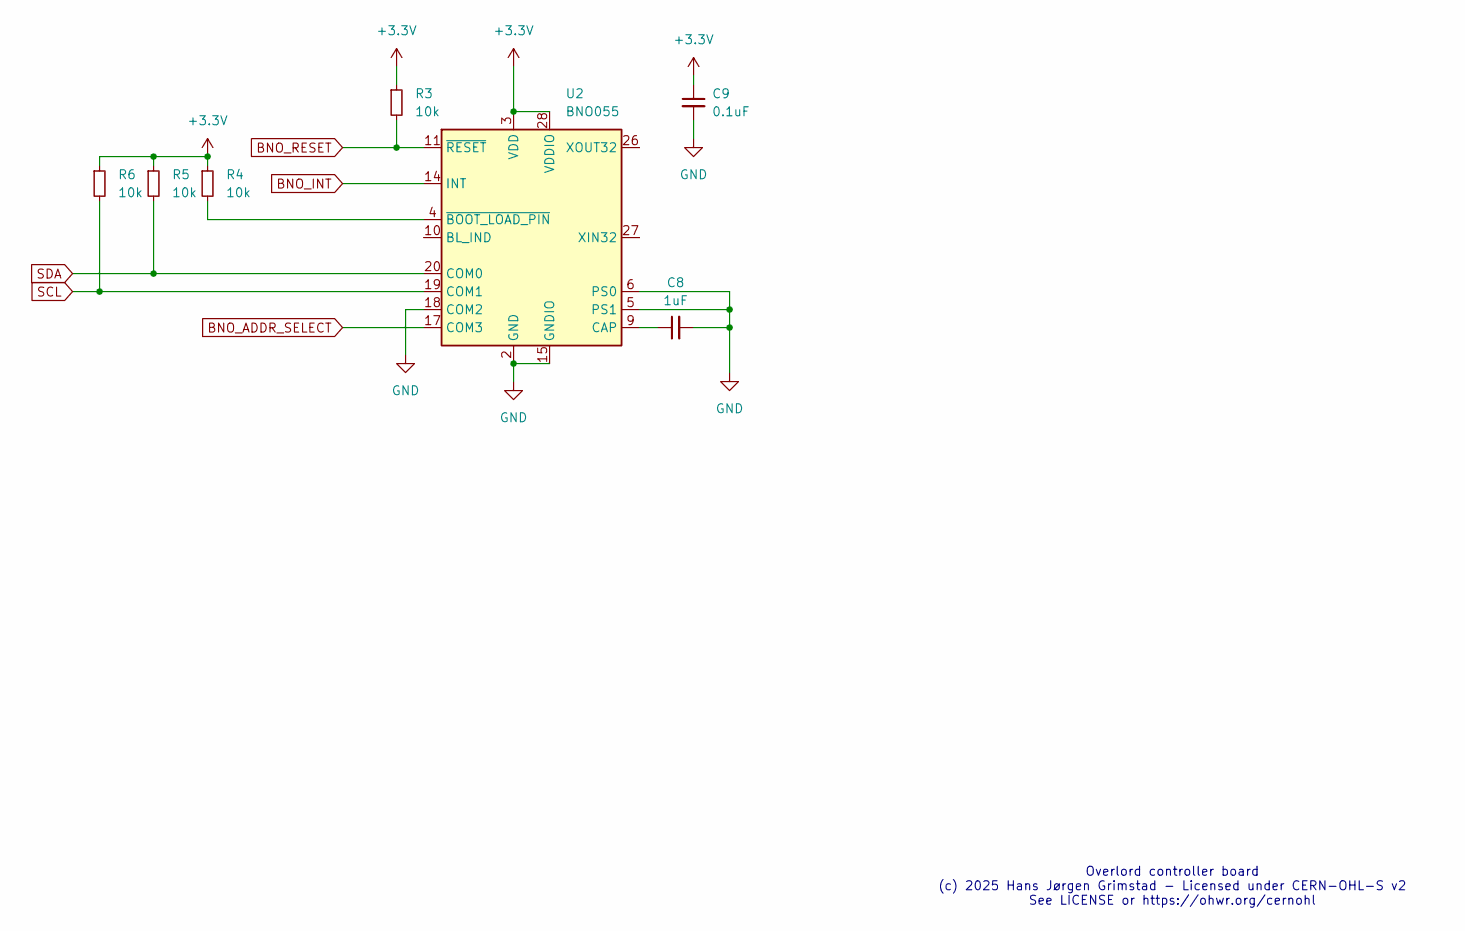
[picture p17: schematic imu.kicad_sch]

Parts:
C8: 1uF; C_0402_1005Metric
C9: 0.1uF; C_0402_1005Metric
R3, R4, R5, R6: 10k; R_0402_1005Metric
U2: BNO055; LGA-28_5.2x3.8mm_P0.5mm

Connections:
+3.3V: C9.1, R3.1, R4.1, R5.1, R6.1, U2.3 (VDD), U2.28 (VDDIO); also elsewhere on the board
BNO_ADDR_SELECT: U2.17 (COM3); also elsewhere on the board
BNO_INT: U2.14 (INT); also elsewhere on the board
BNO_RESET: R3.2, U2.11 (~RESET); also elsewhere on the board
GND: C8.2, C9.2, U2.2 (GND), U2.5 (PS1), U2.6 (PS0), U2.15 (GNDIO), U2.16 (GNDIO), U2.18 (COM2), U2.25 (GNDIO); also elsewhere on the board
unnamed: C8.1, U2.9 (CAP)
unnamed: R4.2, U2.4 (~BOOT_LOAD_PIN)
SCL: R6.2, U2.19 (COM1); also elsewhere on the board
SDA: R5.2, U2.20 (COM0); also elsewhere on the board

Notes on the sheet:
Overlord controller board (c) 2025 Hans Jørgen Grimstad - Licensed under CERN-OHL-S v2 See LICENSE or https://ohwr.org/cernohl

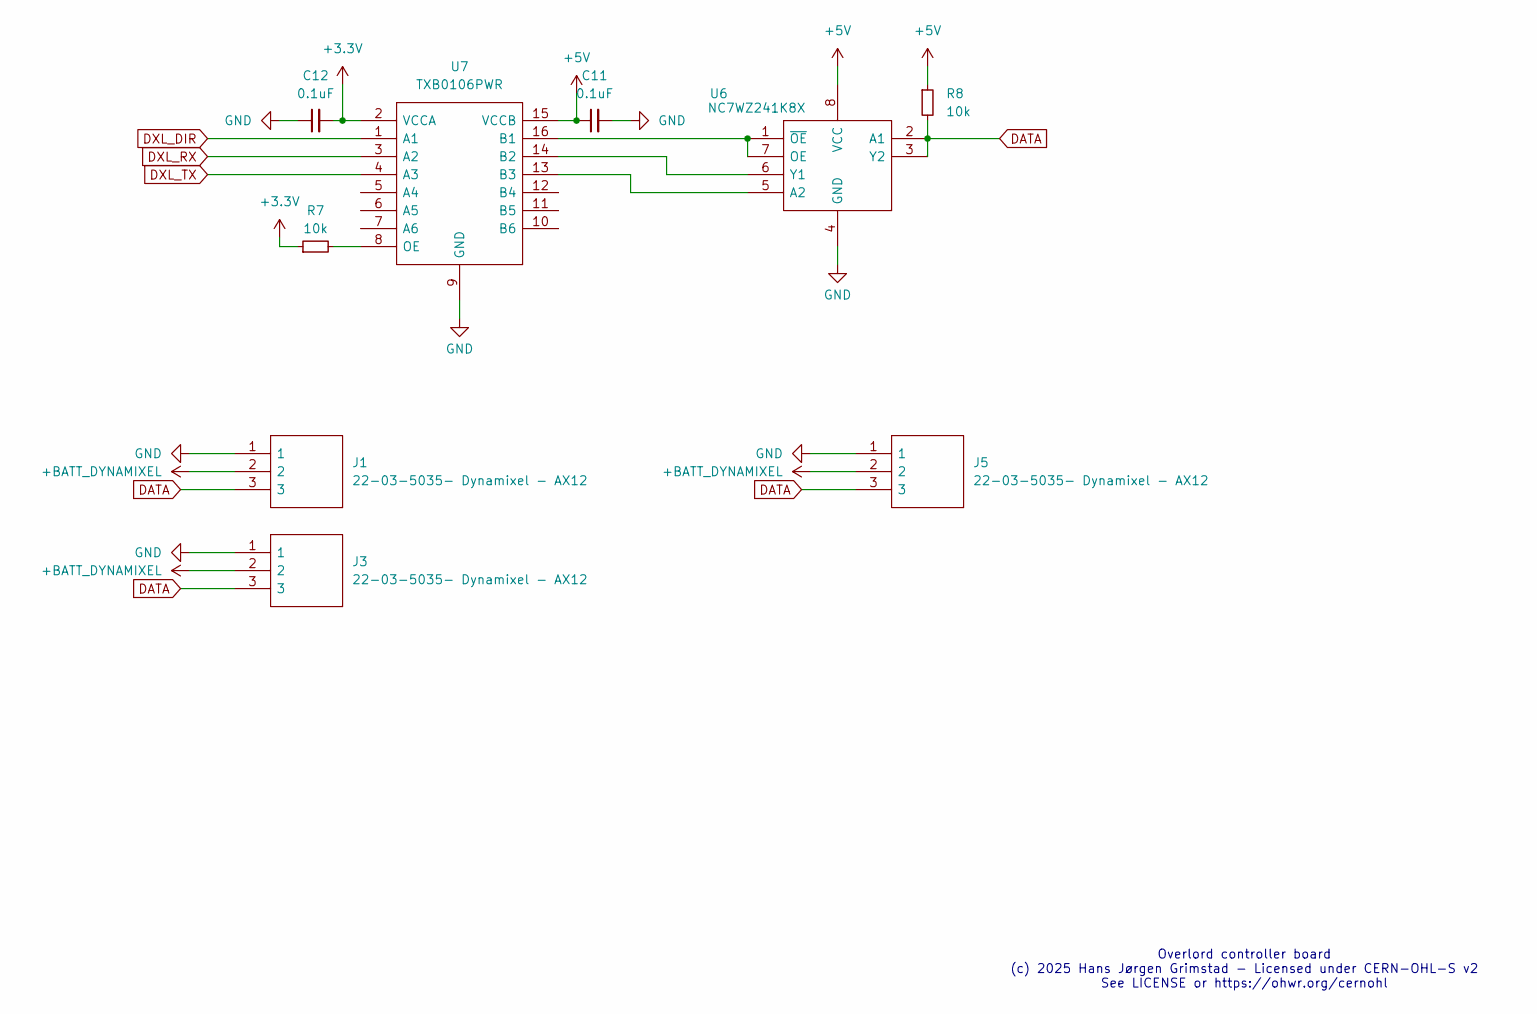
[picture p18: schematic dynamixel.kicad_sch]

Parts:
C11, C12: 0.1uF; C_0603_1608Metric
J1, J3, J5: 22-03-5035- Dynamixel - AX12; SHDR3W60P0X250_1X3_990X490X590P; Mouser Part Number 538-22-03-5035
R7, R8: 10k; R_0402_1005Metric
U6: NC7WZ241K8X; SOP50P310X90-8N; Mouser Part Number 512-NC7WZ241K8X
U7: TXB0106PWR; SOP65P640X120-16N; Mouser Part Number 595-TXB0106PWR

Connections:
+3.3V: C12.2, R7.1, U7.2 (VCCA); also elsewhere on the board
+5V: C11.1, R8.1, U6.8 (VCC), U7.15 (VCCB); also elsewhere on the board
+BATT_DYNAMIXEL: J1.2, J3.2, J5.2; also elsewhere on the board
DATA: J1.3, J3.3, J5.3, R8.2, U6.2 (A1), U6.3 (Y2)
DXL_DIR: U7.1 (A1); also elsewhere on the board
DXL_RX: U7.3 (A2); also elsewhere on the board
DXL_TX: U7.4 (A3); also elsewhere on the board
GND: C11.2, C12.1, J1.1, J3.1, J5.1, U6.4 (GND), U7.9 (GND); also elsewhere on the board
unnamed: U6.5 (A2), U7.13 (B3)
unnamed: U6.1 (~OE), U6.7 (OE), U7.16 (B1)
unnamed: U6.6 (Y1), U7.14 (B2)
unnamed: R7.2, U7.8 (OE)

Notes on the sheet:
Overlord controller board (c) 2025 Hans Jørgen Grimstad - Licensed under CERN-OHL-S v2 See LICENSE or https://ohwr.org/cernohl

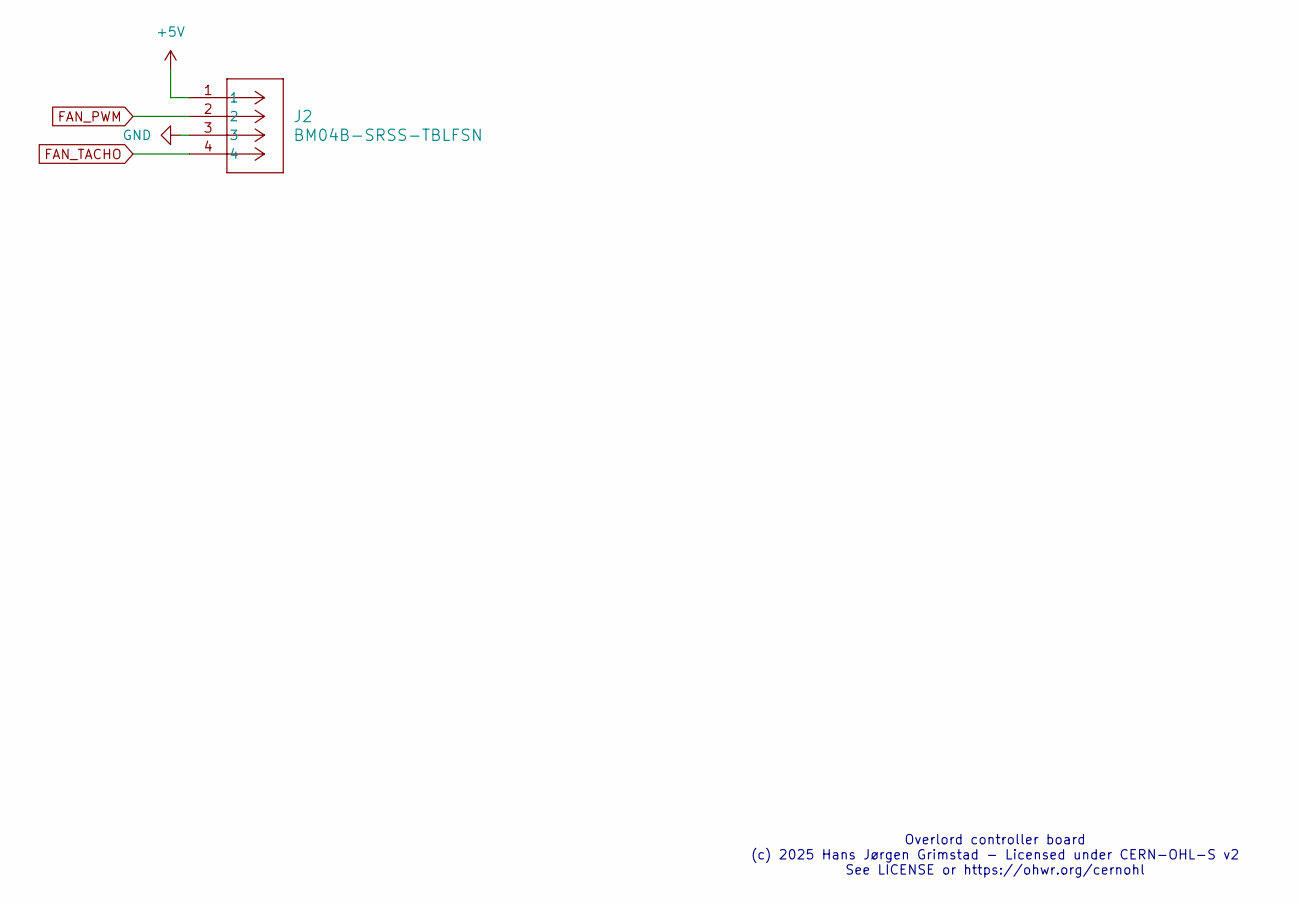
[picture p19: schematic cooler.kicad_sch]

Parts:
J2: BM04B-SRSS-TBLFSN; CONN4_BM04B-SRSS_JST

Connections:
+5V: J2.1; also elsewhere on the board
FAN_PWM: J2.2; also elsewhere on the board
FAN_TACHO: J2.4; also elsewhere on the board
GND: J2.3; also elsewhere on the board

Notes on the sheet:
Overlord controller board (c) 2025 Hans Jørgen Grimstad - Licensed under CERN-OHL-S v2 See LICENSE or https://ohwr.org/cernohl

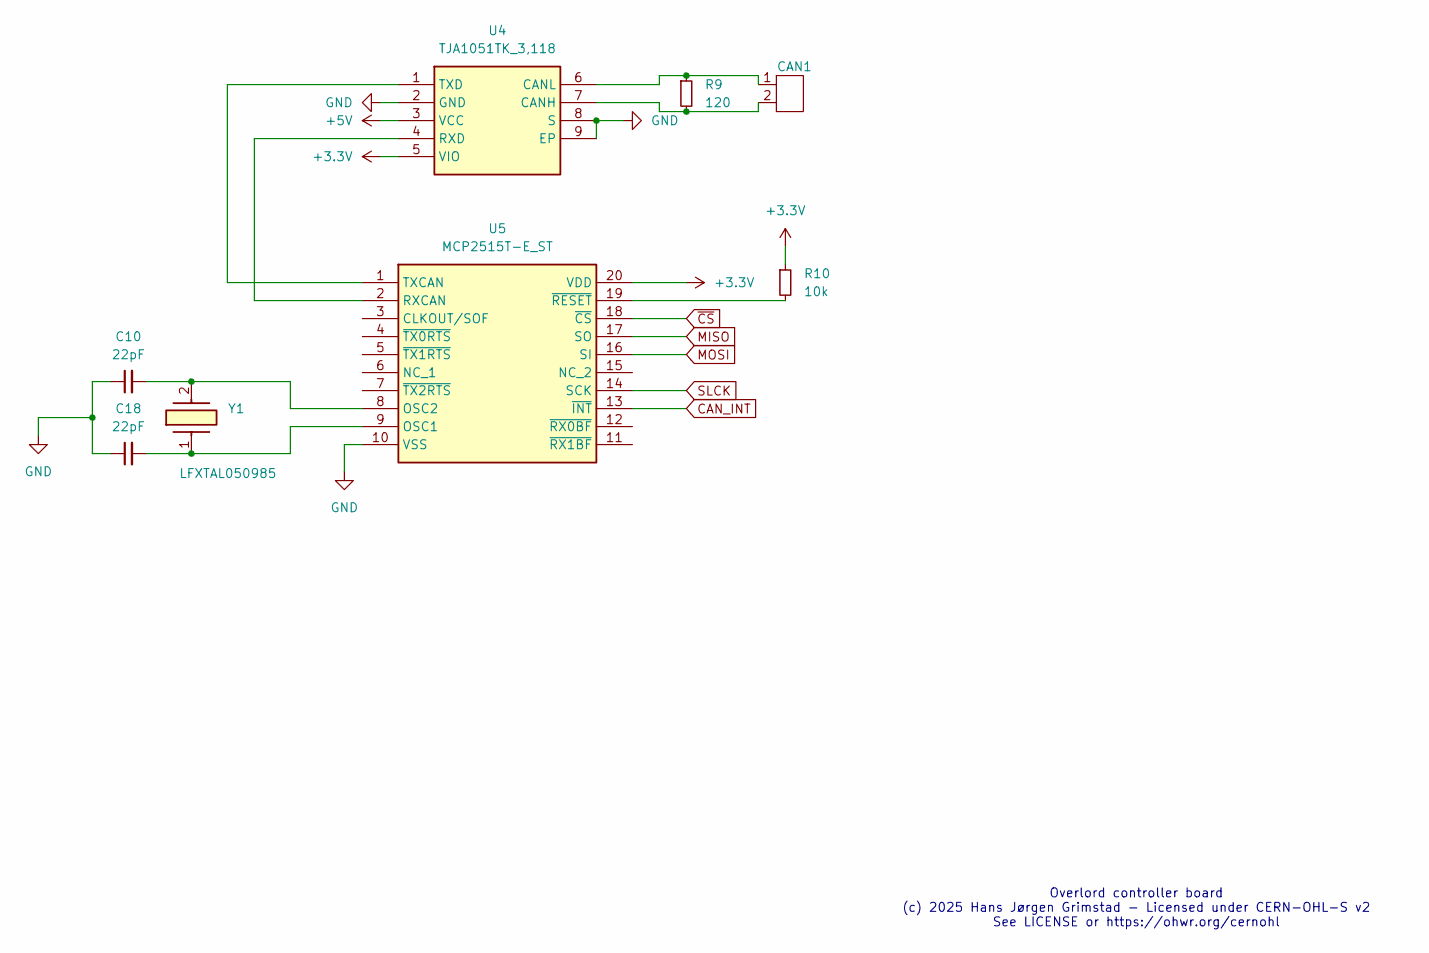
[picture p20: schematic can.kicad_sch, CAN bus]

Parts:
C10, C18: 22pF; C_0402_1005Metric
CAN1: MOLEX-39531-5002
R9: 120; R_1218_3246Metric
R10: 10k; R_0402_1005Metric
U4: TJA1051TK_3,118; HVSON-8-1EP_3x3mm_P0.65mm_EP1.6x2.4mm; Mouser Part Number 771-TJA1051TK/3118
U5: MCP2515T-E_ST; SOP65P640X120-20N; Mouser Part Number 579-MCP2515T-E/ST
Y1: LFXTAL050985; LFXTAL050985Bulk; Mouser Part Number 449-LFXTAL050985BULK

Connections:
+3.3V: R10.1, U4.5 (VIO), U5.20 (VDD); also elsewhere on the board
+5V: U4.3 (VCC); also elsewhere on the board
CAN_INT: U5.13 (~INT); also elsewhere on the board
GND: C10.1, C18.1, U4.2 (GND), U4.8 (S), U4.9 (EP), U5.10 (VSS); also elsewhere on the board
MISO: U5.17 (SO); also elsewhere on the board
MOSI: U5.16 (SI); also elsewhere on the board
unnamed: CAN1.2, R9.2, U4.7 (CANH)
unnamed: CAN1.1, R9.1, U4.6 (CANL)
unnamed: U4.4 (RXD), U5.2 (RXCAN)
unnamed: U4.1 (TXD), U5.1 (TXCAN)
unnamed: C18.2, U5.9 (OSC1), Y1.1
unnamed: C10.2, U5.8 (OSC2), Y1.2
unnamed: R10.2, U5.19 (~RESET)
SLCK: U5.14 (SCK); also elsewhere on the board
~CS: U5.18 (~CS); also elsewhere on the board

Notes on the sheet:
Overlord controller board (c) 2025 Hans Jørgen Grimstad - Licensed under CERN-OHL-S v2 See LICENSE or https://ohwr.org/cernohl

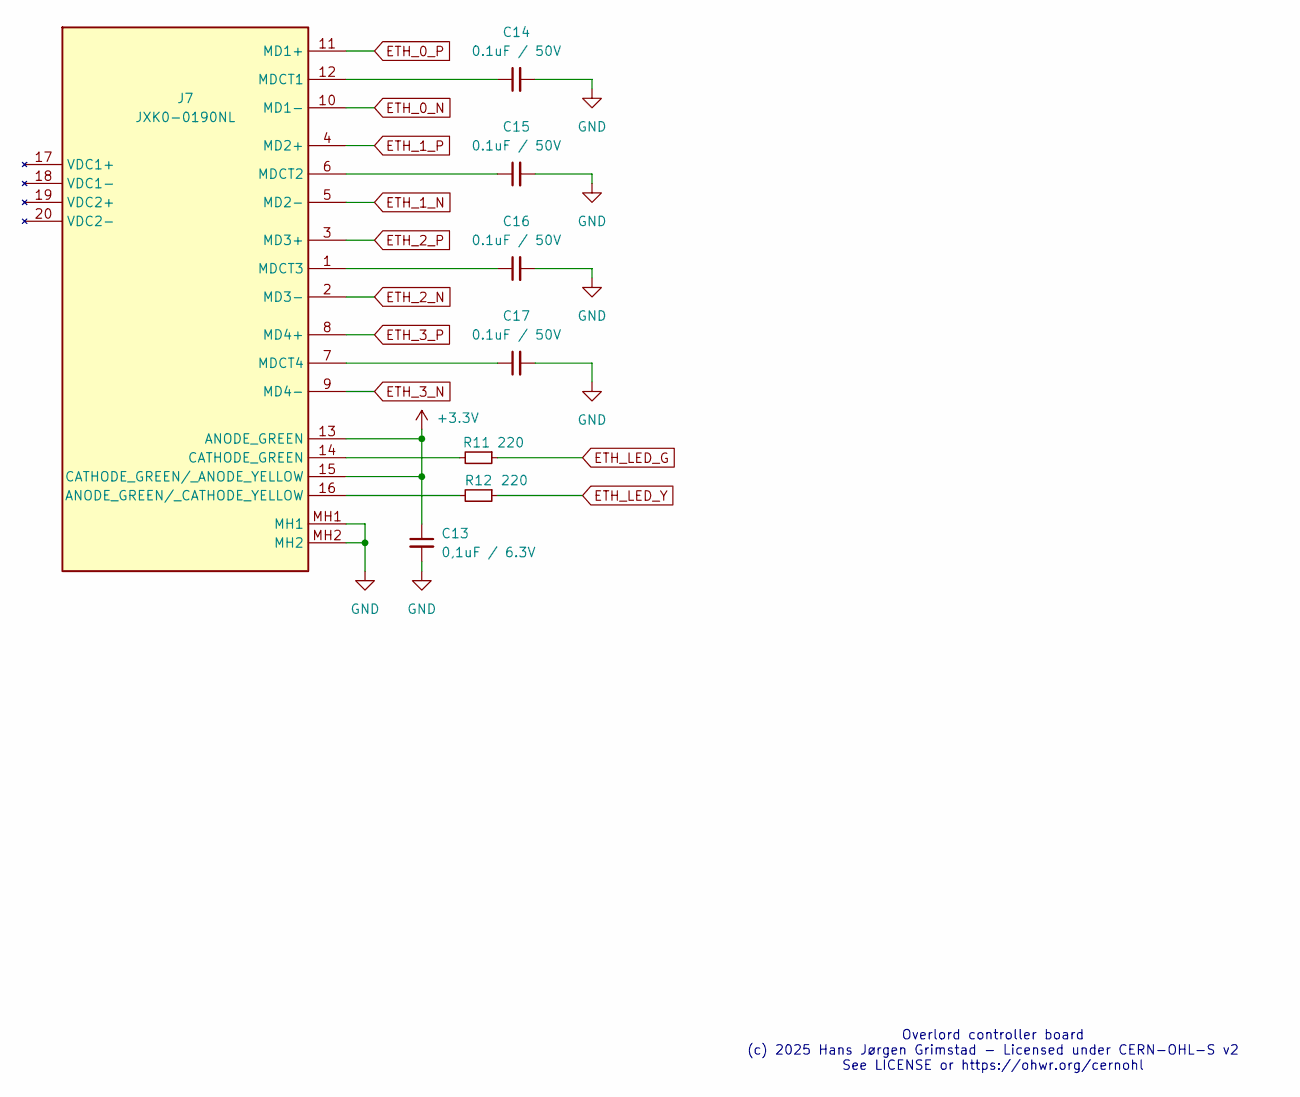
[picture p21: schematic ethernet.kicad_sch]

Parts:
C13: 0,1uF / 6.3V; C_0603_1608Metric
C14, C15, C16, C17: 0.1uF / 50V; C_0603_1608Metric
J7: JXK0-0190NL; CONN20_0-0190NL_PUL; Mouser Part Number 673-JXK0-0190NL
R11, R12: 220; R_0402_1005Metric

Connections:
+3.3V: C13.1, J7.13 (ANODE_GREEN), J7.15 (CATHODE_GREEN/_ANODE_YELLOW); also elsewhere on the board
ETH_0_N: J7.10 (MD1-); also elsewhere on the board
ETH_0_P: J7.11 (MD1+); also elsewhere on the board
ETH_1_N: J7.5 (MD2-); also elsewhere on the board
ETH_1_P: J7.4 (MD2+); also elsewhere on the board
ETH_2_N: J7.2 (MD3-); also elsewhere on the board
ETH_2_P: J7.3 (MD3+); also elsewhere on the board
ETH_3_N: J7.9 (MD4-); also elsewhere on the board
ETH_3_P: J7.8 (MD4+); also elsewhere on the board
ETH_LED_G: R11.1; also elsewhere on the board
ETH_LED_Y: R12.1; also elsewhere on the board
GND: C13.2, C14.2, C15.2, C16.2, C17.2, J7.MH1, J7.MH2; also elsewhere on the board
unnamed: J7.16 (ANODE_GREEN/_CATHODE_YELLOW), R12.2
unnamed: J7.14 (CATHODE_GREEN), R11.2
unnamed: C14.1, J7.12 (MDCT1)
unnamed: C15.1, J7.6 (MDCT2)
unnamed: C16.1, J7.1 (MDCT3)
unnamed: C17.1, J7.7 (MDCT4)

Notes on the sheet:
Overlord controller board (c) 2025 Hans Jørgen Grimstad - Licensed under CERN-OHL-S v2 See LICENSE or https://ohwr.org/cernohl

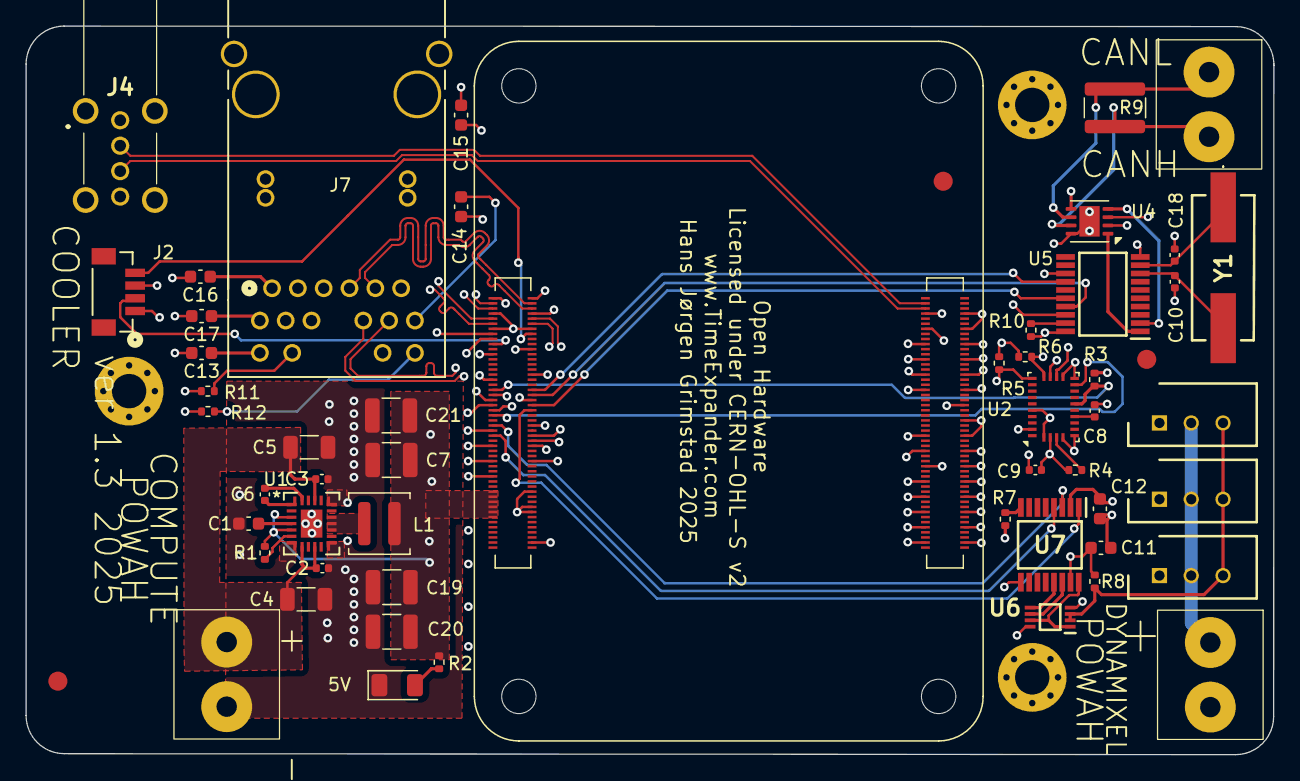
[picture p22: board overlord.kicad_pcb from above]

Board: 6 copper layers, 98.1 x 57.3 mm, 52 parts (0 on the bottom side), 58 nets.

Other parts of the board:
5V: APTR3216QBC_D; LED_1206_3216Metric

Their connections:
GND: 5V.1 (K); also elsewhere on the board
unnamed 35: 5V.2 (A); also elsewhere on the board

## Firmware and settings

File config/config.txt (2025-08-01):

# For more options and information see
# http://rptl.io/configtxt
# Some settings may impact device functionality. See link above for details

# Uncomment some or all of these to enable the optional hardware interfaces

#dtparam=i2s=on

# Enable audio (loads snd_bcm2835)
# dtparam=audio=on

# Additional overlays and parameters are documented
# /boot/firmware/overlays/README

# Automatically load overlays for detected cameras
# camera_auto_detect=1

# Automatically load overlays for detected DSI displays
# display_auto_detect=1

# Automatically load initramfs files, if found
auto_initramfs=1

# Enable DRM VC4 V3D driver
#dtoverlay=vc4-kms-v3d
#max_framebuffers=2

# Don't have the firmware create an initial video= setting in cmdline.txt.
# Use the kernel's default instead.
disable_fw_kms_setup=1

# Run in 64-bit mode
arm_64bit=1

# Disable compensation for displays with overscan
disable_overscan=1

# Run as fast as firmware / board allows
arm_boost=1

[cm4]
# Enable host mode on the 2711 built-in XHCI USB controller.
# This line should be removed if the legacy DWC2 controller is required
# (e.g. for USB device mode) or if USB support is not required.
otg_mode=1

[cm5]

# IMU
dtparam=i2c_arm=on

# BNO055 RESET
gpio=7=op,dh

# BNO055 ADDR SELECT
gpio=24=op,dh

# UART and Dynamixel
enable_uart=1
dtoverlay=uart0
dtoverlay=disable-bt
gpio=22=op,dl

# CAN
dtparam=spi=on
dtoverlay=dwc2,dr_mode=host
dtparam=ant1
dtoverlay=spi0-1cs,cs0_pin=8,sclk_pin=11,miso_pin=9,mosi_pin=10
dtoverlay=gpio-pullup,gpiopin=5
dtoverlay=mcp2515-can0,oscillator=16000000,cs_pin=8,sclk_pin=11,miso_pin=9,mosi_pin=10,interrupt=5

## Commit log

2025-08-01 Updated config.txt with correct uart overlay
    [config.txt]
2025-08-01 Added IMU example (chip ID + heading vector)
    * Updated various README files
2025-08-01 Updated logging in IMU example
    * Updated README
2025-08-05 Added PDF version of schematic
    * Added comment in schematic regarding CAN bitrate
    [can.kicad_sch]
